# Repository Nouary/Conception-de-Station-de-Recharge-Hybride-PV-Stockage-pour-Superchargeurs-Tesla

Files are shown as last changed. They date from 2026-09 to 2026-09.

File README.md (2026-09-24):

# Conception et Dimensionnement d'une Station de Recharge Hybride (PV + Stockage) pour Superchargeurs Tesla

<p align="center">
  
  
  
  
  
  
</p>

---

## 📌 Présentation du Projet

Ce projet présente l'étude complète d'ingénierie, de dimensionnement électrotechnique, de modélisation 3D, de simulation technico-économique et de stratégie de contrôle intelligent (**Energy Management System - EMS**) pour la conversion de la **Station Supercharger Tesla** située sur la **Route de Sefrou à Fès (Maroc)**, adjacente au magasin **KITEA Giant**, en un **Hub Énergétique Hybride et Intelligent**.

<p align="center">
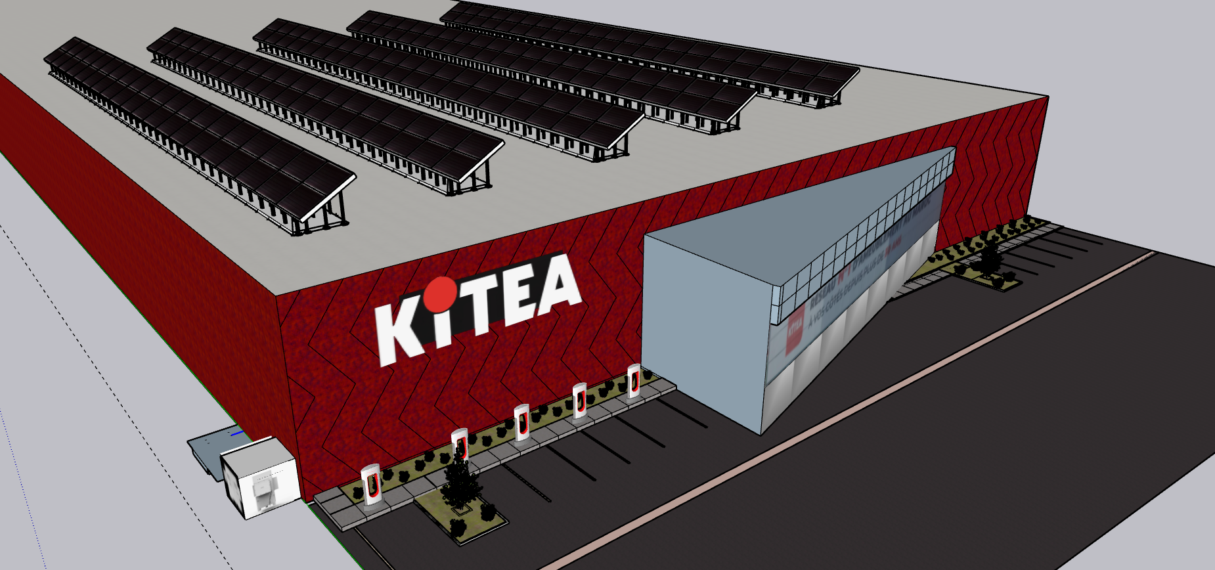
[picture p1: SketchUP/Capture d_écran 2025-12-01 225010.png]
Modélisation 3D SketchUp de la Toiture Solaire KITEA et de la Station Supercharger Tesla
  
  <br />
  <em>Modélisation 3D SketchUp : Implantation des 180 modules solaires sur la toiture KITEA Giant, conteneur BESS Huawei LUNA2000 et bornes Tesla Superchargers.</em>
</p>

### ⚠️ Problématique
Les bornes de recharge ultra-rapides Tesla (Superchargers V2/V3) délivrent des appels de puissance instantanés très élevés (**jusqu'à 150 kW par borne**). L'exploitation simultanée de ces bornes engendre :
1. **Une saturation du réseau électrique local (RADEEF)** et un risque de surcharge thermique sur le transformateur moyenne/basse tension.
2. **Des pénalités financières sévères** liées aux dépassements de la puissance souscrite lors des pointes de demande.

### 💡 Solution Proposée
Mise en place d'une architecture en **Couplage AC** exploitant la grande surface de toiture disponible du bâtiment KITEA pour la génération solaire photovoltaïque, couplée à un système de stockage par batteries industrielles (**BESS**) situé aux abords des bornes. L'ensemble est synchronisé en temps réel par un automate de gestion de l'énergie (**EMS**) assurant l'écrêtage des pointes (*Peak Shaving*) et l'arbitrage tarifaire.

---

## ⚡ Spécifications Techniques du Système

### 1. Générateur Photovoltaïque (Toiture KITEA)
* **Technologie des cellules :** Monocristallin n-type bifacial haute efficacité.
* **Modules solaires :** 180 × **JA Solar JAM66D46-LB 740 W**.
* **Puissance crête installée :** **133,2 kWc**.
* **Onduleur de chaîne :** 1 × **Huawei SUN2000-100KTL-M1** (Puissance nominale : 100 kW AC, 10 MPPT indépendants, rendement max 98,8%).
* **Configuration électrique :** 10 chaînes (*strings*) de 18 modules en série (1 chaîne par MPPT).
  * $V_{oc} \text{ à } -5^\circ\text{C} = 53,54\text{ V} \implies V_{\text{chaîne}} = 963,7\text{ V} \le 1100\text{ V}$ (Conforme).
  * $I_{sc} = 18,73\text{ A} \le I_{\text{sc max MPPT}} (40\text{ A})$ (Conforme).
  * Ratio DC/AC : $\frac{133,2\text{ kWc}}{100\text{ kW}} = \mathbf{1,33}$ (Dimensionnement optimal).

### 2. Système de Stockage d'Énergie BESS (Station Tesla)
* **Équipement :** 2 × **Huawei LUNA2000-200KWH-2H1** Smart String ESS.
* **Capacité nominale totale :** **400 kWh** (~387 kWh utiles à 90% DoD).
* **Puissance de décharge continue :** **200 kW** (Courant max : 144,3 A triphasé 400 V).
* **Convertisseurs :** Smart Rack Controller (**SRC**) stabilisant le bus DC à 1100 V et Power Conversion System (**PCS**) injectant en triphasé 400 V.
* **Autonomie :** Capacité suffisante pour assurer la recharge complète de **~6 véhicules électriques** sans solliciter le réseau.

### 3. Câblage et Raccordement Électrique
* **Liaison Toiture KITEA $\rightarrow$ Station Tesla :** Distance de **100 m**.
* **Câble de puissance AC retenu :** Câble cuivre **U-1000 R2V 4×70 mm²** (chute de tension $\Delta U < 3\%$, sécurisant la section théorique de 50 mm²).
* **Point de couplage commun (PCC) :** TGBT Station (Bus AC 400 V triphasé).
* **Protections :** Disjoncteurs boîtiers moulés (MCCB) calibrés à 160 A avec sélectivité ampèremétrique et chronométrique.

---

## 🧠 Stratégie de Contrôle Intelligent (EMS)

L'installation est pilotée par le **Huawei SmartLogger 3000A**, communicant via le protocole **Modbus-RTU (RS-485)** avec l'onduleur PV, les contrôleurs de batterie SRC et le compteur d'énergie bidirectionnel **DTSU666-H** (équipé de 3 transformateurs de courant 5A).

```
                      ┌───────────────────────────────┐
                      │    Réseau Public (RADEEF)     │
                      └──────────────┬────────────────┘
                                     │  Transformateurs de courant (TC)
                                     ▼  + Smart Power Sensor DTSU666-H
                      ┌───────────────────────────────┐
                      │    TGBT Station (Bus AC)      │
                      └───┬───────────┬───────────┬───┘
                          │           │           │
       Puissance Solaire  │           │           │  Décharge Peak Shaving
                          ▼           ▼           ▼
┌───────────────────────────┐   ┌───────────┐   ┌───────────────────────────┐
│ Onduleur Huawei           │   │  Bornes   │   │ BESS Huawei LUNA2000      │
│ SUN2000-100KTL-M1         │   │   Tesla   │   │ PCS + SRC (200 kW/400 kWh)│
│ (133.2 kWc PV Toiture)    │   │  Super-   │   └─────────────┬─────────────┘
└─────────────┬─────────────┘   │  chargers │                 │
              │                 └───────────┘                 │
              └───────────────┐               ┌───────────────┘
                     RS-485   │               │   RS-485
                              ▼               ▼
                      ┌───────────────────────────────┐
                      │   Huawei SmartLogger 3000A    │
                      │    (Cerveau EMS Centralisé)   │
                      └───────────────────────────────┘
```

### Modes de Fonctionnement Prioritaires :
1. **Écrêtage des pointes (Peak Shaving) :** Dès que la demande des Superchargeurs franchit le seuil critique contractuel (ex. 100 kW), le SmartLogger déclenche instantanément la décharge des batteries LUNA2000 à concurrence de 200 kW pour soulager le réseau.
2. **Arbitrage Tarifaire (Time-of-Use) :** Injection de l'énergie stockée durant les heures pleines/pointe en soirée pour éviter la tarification élevée du kWh.
3. **Autoconsommation & Compensation Carbone :** Priorité absolue à la consommation directe des électrons verts produits sur site.

---

## 📊 Résultats des Simulations SAM (System Advisor Model)

Les simulations de performance ont été exécutées avec le logiciel **SAM (NREL)** en utilisant les données météorologiques horaires typiques de Fès :

| Indicateur Clé (KPI) | Valeur Simulée |
| :--- | :--- |
| **Production annuelle nette AC (Année 1)** | **127 169 kWh** |
| **Ratio de Performance (PR)** | **0,77 (77,0%)** |
| **Productible spécifique** | **954 kWh/kWc** |
| **Facteur de charge DC** | **10,9%** |
| **Rendement de cycle batterie (Roundtrip)** | **96,37%** |
| **Taux de charge batterie par le système PV** | **100,0%** |

### Graphiques de Simulation

<table align="center">
  <tr>
    <td align="center" width="50%">
      <b>Diagramme des Pertes Systémiques (Sankey)</b><br />
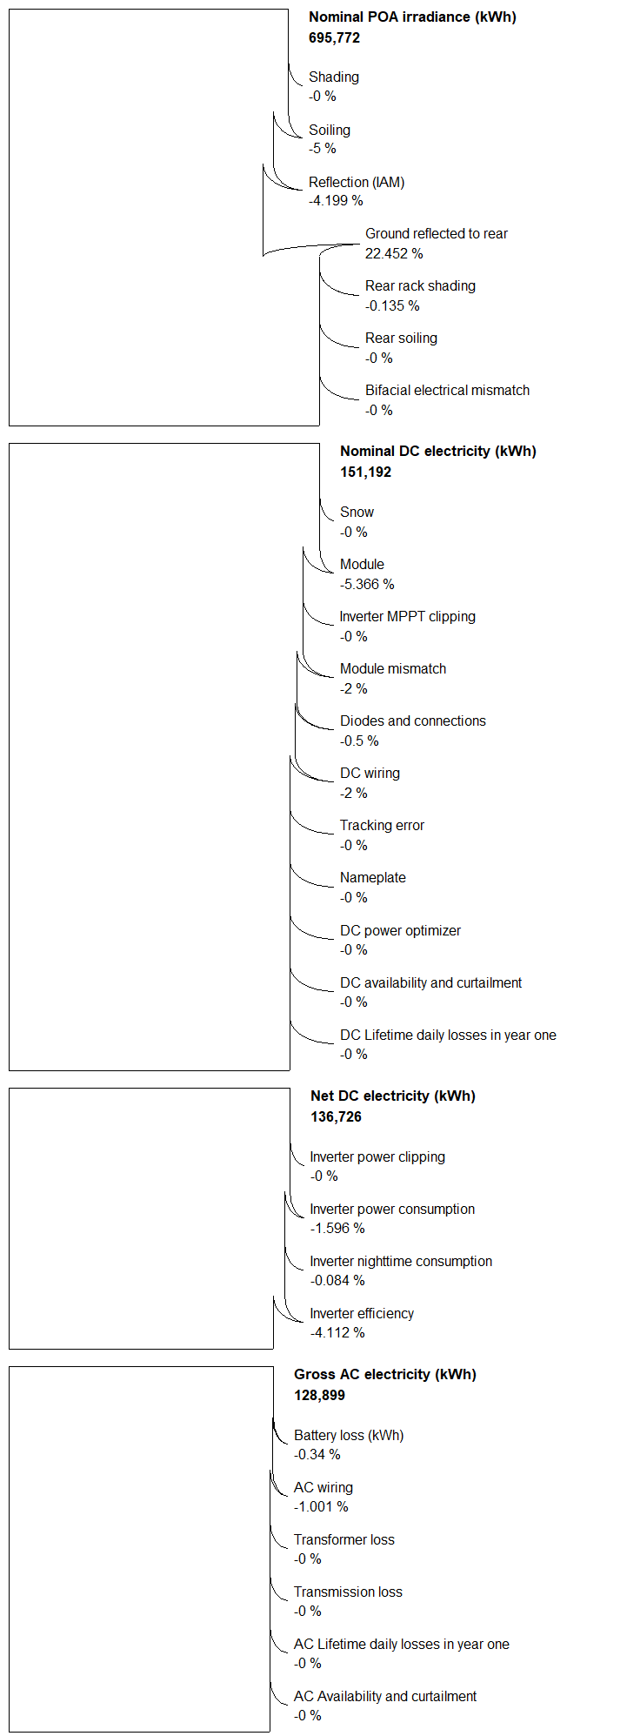
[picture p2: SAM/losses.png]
SAM System Losses
      
    </td>
    <td align="center" width="50%">
      <b>Production AC Mensuelle (Année 1)</b><br />
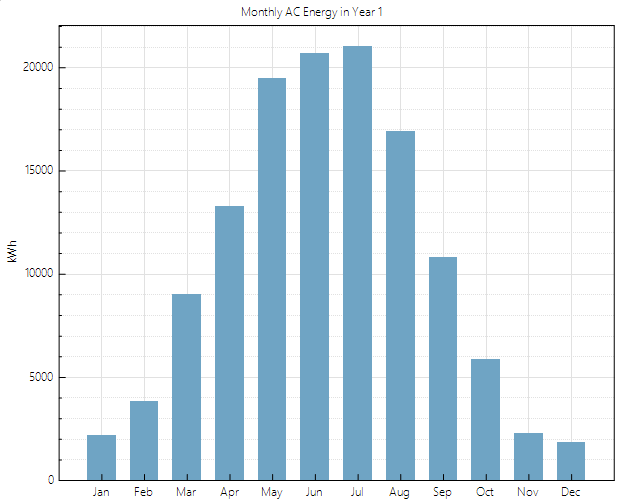
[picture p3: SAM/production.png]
Production Mensuelle
      
    </td>
  </tr>
  <tr>
    <td align="center" colspan="2">
      <b>Mix Énergétique & Couverture de la Charge (PV vs Batterie vs Réseau)</b><br />
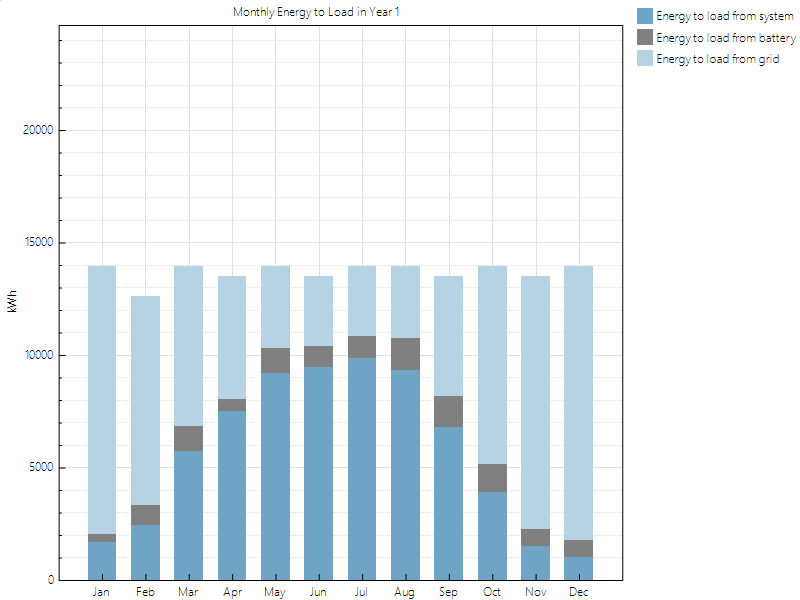
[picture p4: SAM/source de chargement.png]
Mix Énergétique
      
    </td>
  </tr>
</table>

---

## 💰 Analyse Économique & Rentabilité

### 1. Bilan d'Investissement (CAPEX)

| Désignation | Quantité | Prix Unitaire H.T. (MAD) | Montant Total H.T. (MAD) |
| :--- | :---: | :---: | :---: |
| Modules JA Solar JAM66D46-LB 740W | 180 | 1 200,00 | 216 000,00 |
| Câble solaire & AC (340 m) | 1 lot | - | 22 100,00 |
| Structure de montage toiture & brides | 1 lot | - | 106 560,00 |
| Onduleur Huawei SUN2000-100KTL-M1 | 1 | 50 000,00 | 50 000,00 |
| Huawei SmartLogger 3000A | 1 | 7 000,00 | 7 000,00 |
| Transformateurs de courant (TC) | 3 | 1 200,00 | 3 600,00 |
| Compteur intelligent DTSU666-H | 1 | 3 500,00 | 3 500,00 |
| Huawei LUNA2000-200KWH-2H1 (BESS) | 2 | 800 000,00 | 1 600 000,00 |
| Ingénierie, installation & mise en service | 1 lot | - | 159 840,00 |
| **TOTAL CAPEX H.T.** | | | **2 168 600,00 MAD** |
| **TOTAL CAPEX T.T.C. (TVA 20%)** | | | **2 602 320,00 MAD** |

### 2. Indicateurs Financiers

<p align="center">
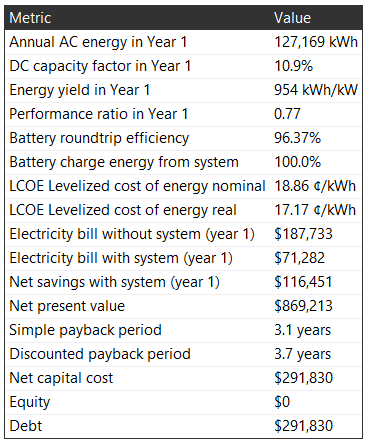
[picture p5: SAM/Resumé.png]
SAM Financial Summary
  
</p>

* **Facture d'électricité sans le système :** 2 104 502 MAD/an ($187 733 USD)
* **Facture d'électricité avec le système :** 798 438 MAD/an ($71 282 USD)
* **Économies nettes annuelles :** **1 306 064 MAD/an** ($116 451 USD)
* **Temps de retour sur investissement (Simple Payback) :** **3,1 ans** (Discounted Payback : 3,7 ans).
* **Valeur Actuelle Nette (VAN / NPV) sur 25 ans :** **+$869 213 USD** (~ 8,7 Millions MAD).
* **Coût actualisé de l'énergie (LCOE réel) :** **17,17 ¢/kWh**.

---

## 📁 Organisation du Dépôt

```plaintext
├── .gitattributes                                       # Configuration Git LFS (fichiers .skp et .skb)
├── LICENSE                                              # Licence Open-Source MIT
├── README.md                                            # Documentation générale du projet
├── Project Summary.pdf                                  # Synthèse technique et exécutive du projet
├── PV_project.pdf                                       # Rapport d'ingénierie complet détaillé (29 pages)
│
├── Autocad/                                             # Dossier des plans techniques 2D et schémas électriques
│   ├── Support 2D.pdf                                   # Plan de la structure de supportage
│   ├── Support clamps 2D.pdf                            # Détails des brides de serrage (clamps)
│   ├── schema unifilaire commande.pdf                   # Schéma unifilaire du circuit de commande
│   ├── schéma multifilaire commande.pdf                 # Schéma multifilaire de commande
│   ├── schéma unifilaire puissance.pdf                  # Schéma unifilaire du circuit de puissance
│   └── simulations/                                     # Fichiers sources AutoCAD (.dwg, .bak)
│       ├── Support 2D.dwg
│       ├── les vues de systeme.dwg
│       ├── schema unifilaire commande.dwg
│       ├── schema unifilaire puissance.dwg
│       └── schema Multiifilaire puissance.dwg
│
├── SketchUP/                                            # Modélisation 3D de la station et du bâtiment
│   ├── SketchUP.skp                                     # Maquette 3D complète (gérée via Git LFS)
│   ├── SketchUP.skb                                     # Fichier de sauvegarde SketchUp (géré via Git LFS)
│   ├── Capture d_écran 2025-12-01 224916.png            # Rendu toiture KITEA et panneaux
│   └── Capture d_écran 2025-12-01 225010.png            # Rendu complet toiture, station Tesla et BESS
│
├── SAM/                                                 # Modélisation et simulation NREL SAM
│   ├── SAM FINAL.sam                                    # Projet source System Advisor Model
│   ├── losses.png                                       # Diagramme de pertes en cascade (Sankey)
│   ├── production.png                                   # Graphique de production mensuelle AC
│   ├── source de chargement.png                         # Répartition de couverture de charge
│   ├── Resumé.png                                       # Tableau récapitulatif des métriques financières
│   ├── inverter data/                                   # Fiches de caractérisation de l'onduleur (.csv)
│   └── module data/                                     # Fiches de caractérisation des modules (.csv)
│
└── Data sheet and user manual/                          # Fiches techniques et manuels officiels
    ├── SUN2000-100KTL-M1.pdf                            # Onduleur triphasé Huawei 100 kW
    ├── luna2000-200kwhg-2h1-dtatsheet-20230310.pdf      # Système de stockage industriel Huawei LUNA2000
    ├── SmartLogger3000A.pdf                             # Fiche technique du contrôleur de communication
    ├── Manuel d_utilisation, SmartLogger3000.pdf        # Manuel complet d'utilisation SmartLogger
    ├── JAM66D46_715-740_LB_Global_EN_20250709C.pdf      # Module solaire JA Solar 740 W
    ├── dtsu666-h-100a-datasheet.pdf                     # Capteur de puissance intelligent Huawei / Chint
    └── DTSU666-H 100 A and 250 A Smart Power Sensor...  # Manuel de câblage et configuration du compteur
```

---

## 👥 Auteurs & Affiliation Académique

Projet d'ingénierie réalisé au sein de :
* **Institution :** École Nationale des Sciences Appliquées de Fès (**ENSA Fès**) — Université Sidi Mohamed Ben Abdellah (**USMBA**).
* **Département :** Génie Industriel.
* **Filière :** Génie Énergétique et Systèmes Intelligents (**GESI**).
* **Module :** Énergie Solaire Photovoltaïque.

**Auteurs du projet :**
* **NOUARY Lhoussaine** ([@Nouary](https://github.com/Nouary))
* **AZZOUZI Wassim**
* **SAADANI Aymane**

**Sous l'encadrement de :**
* **M. CHAIBI Yassine**

---

## 📄 Licence

Ce projet est sous licence libre et open-source **[MIT](LICENSE)**. Vous êtes libre de consulter, utiliser, adapter et vous inspirer de ces travaux pour vos projets académiques et industriels, sous réserve de mentionner les auteurs originaux.

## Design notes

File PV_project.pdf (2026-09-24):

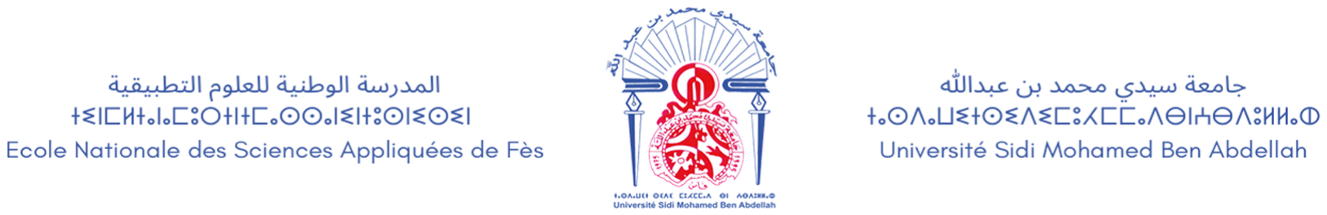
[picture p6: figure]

Département Génie Industriel

FIlière Génie Energétique et Systèmes Intelligents

Energie Solaire Photovoltaique

# Conception et Dimensionnement d’une Station de Recharge Hybride (PV + Stockage) : Stratégie de Gestion Intelligente pour Superchargeurs Tesla

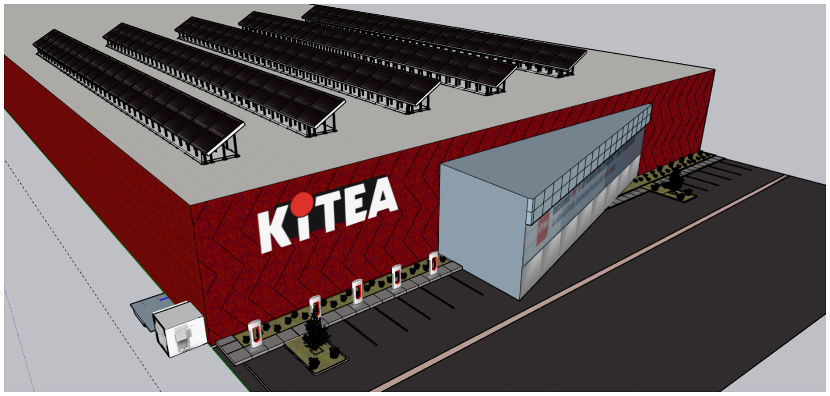
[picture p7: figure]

Réalisé par :

### AZZOUZI Wassim NOUARY Lhoussaine SAADANI Aymane

Encadré par :

### M.CHAIBI Yassine

# Table des matières

1 Introduction | 3
2 Cahier de charges et Dimensionnement du système | 5
3 Étude de compatibilité et vérifications électriques | 12
4 Systèmes intelligents et communications | 15

4.5 Raccordement du compteur DTS U666-H et intégration au SmartLogger . 17

5 Simulation et résultats | 18
6 Etude économique | 27
7 Conclusion | 28

# Table des figures

2.1 Vue de la station Supercharger Tesla à Fès, adjacente au magasin KITEA

2.2 Panneau solaire JA Solar de type JAM66D46 d’une puissance nominale de

2.3 Système de Stockage d’Énergie (ESS) LUNA2000-200KWH-2H1 de Huawei

2.4 Onduleur de type Huawei SUN2000-100KTL-M1 de puissance nominale de

3.1 Schéma illustratif du flux énergétique entre les batteries, le SRC et le PCS. 14

5.1 Plan de calepinage de la toiture KITEA et positionnement des équipements. 18

5.3 Schéma électrique Multifilaire détaillé (Liaison Zone 1 Toiture - Zone 2

5.4 Architecture du système de contrôle-commande (SmartLogger et communi-

5.5 Synoptique des flux de puissance : Production, Stockage et Consommation. 22 5.6 Diagramme des pertes du système (Irradiance POA vers Énergie AC Nette). 23

5.8 Répartition mensuelle de la couverture de charge (PV vs Batterie vs Réseau). 25

# Liste des tableaux

# Chapitre 1

# Introduction

## 1.1 Contexte

La Station Supercharger Tesla de la Route de Sefrou à Fès, adjacente au magasin KITEA Giant, constitue un point stratégique pour la mobilité électrique dans la région. Équipée de bornes de recharge ultra-rapides (Superchargers V2/V3), la station est capable de délivrer jusqu’à 150 kW par borne de recharge, permettant une recharge très rapide pour les utilisateurs de véhicules électriques.
Ces charges massives créent des contraintes sur le réseau électrique local et peuvent engendrer des coûts importants pour l’opérateur en cas de dépassement de puissance. Face à ces défis, l’intégration d’une solution hybride combinant production solaire et stockage d’énergie apparaît comme une approche stratégique. Elle permet non seulement de réduire la dépendance au réseau, mais aussi d’améliorer la durabilité énergétique et de contribuer aux objectifs de transition énergétique régionale.

## 1.2 Problématique et objectifs

L’exploitation de la station telle qu’elle existe actuellement présente deux principaux défis :
— Saturation du réseau : Le transformateur local risque d’être surchargé lors des recharges simultanées.
— Coûts élevés : Les pénalités liées aux dépassements de puissance augmentent significativement les factures d’électricité.
L’objectif de ce projet est de concevoir une station de recharge hybride intelligente combinant production solaire et stockage industriel, afin de :
— Réduire la charge instantanée sur le réseau.
— Optimiser l’usage de l’énergie renouvelable.
— Minimiser les coûts d’exploitation tout en favorisant une approche durable.

## 1.3 Méthodologie

Pour atteindre ces objectifs, le projet a suivi les étapes suivantes :
1. Étude du site : Analyse de la demande en énergie et des caractéristiques des bornes Tesla.

2. Dimensionnement du système photovoltaïque : Calcul de la capacité nécessaire pour la production solaire sur la toiture du KITEA.
3. Conception du stockage industriel : Sélection des batteries et définition de leur puissance et autonomie pour répondre aux besoins de pointe.
4. Intégration et gestion intelligente : Développement d’une stratégie EMS (Energy Management System) pour piloter le peak shaving, l’arbitrage et la compensation carbone.

# Chapitre 2

# Cahier de charges et Dimensionnement du système

## 2.1 Cahier de charges

— Localisation du projet : Station Supercharger Tesla située sur la Route de Sefrou à Fès, adjacente au magasin KITEA Giant.
— Nombre de véhicules souhaités rechargés par jour via l’énergie photovoltaïque : 10 véhicules par jour.
— Support d’installation photovoltaïque : Utilisation de la toiture du magasin KITEA pour l’installation du champ solaire.
— Rentabilité du projet :
— Réduction des coûts énergétiques grâce à l’autoconsommation solaire.
— Diminution des pénalités liées au dépassement de puissance.
— Amélioration du retour sur investissement grâce à une production solaire gratuite et à la baisse de la dépendance vis-à-vis du réseau électrique.
— Valorisation environnementale et amélioration de l’image « verte » de la station.

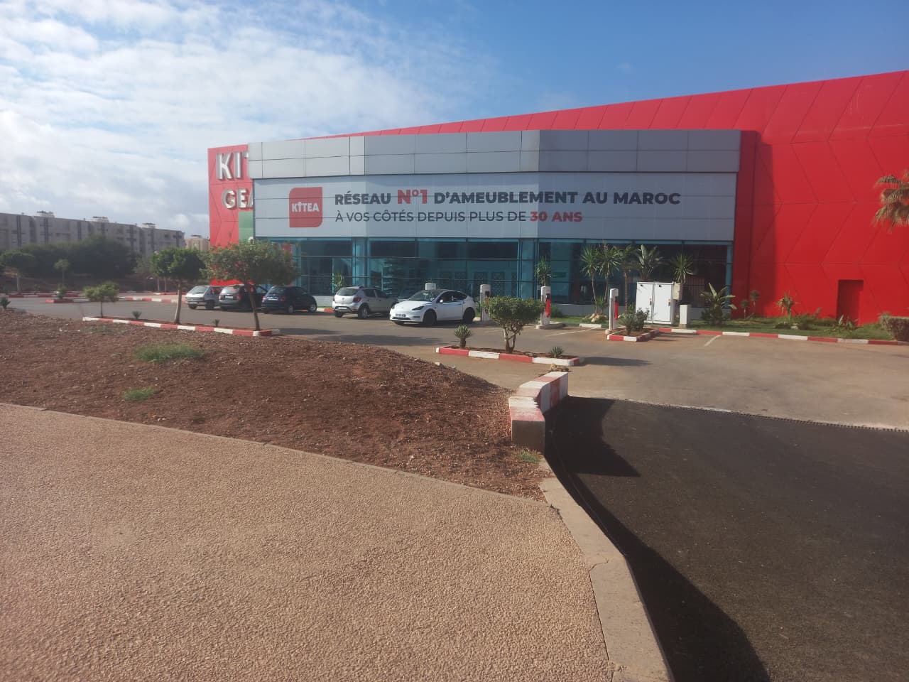
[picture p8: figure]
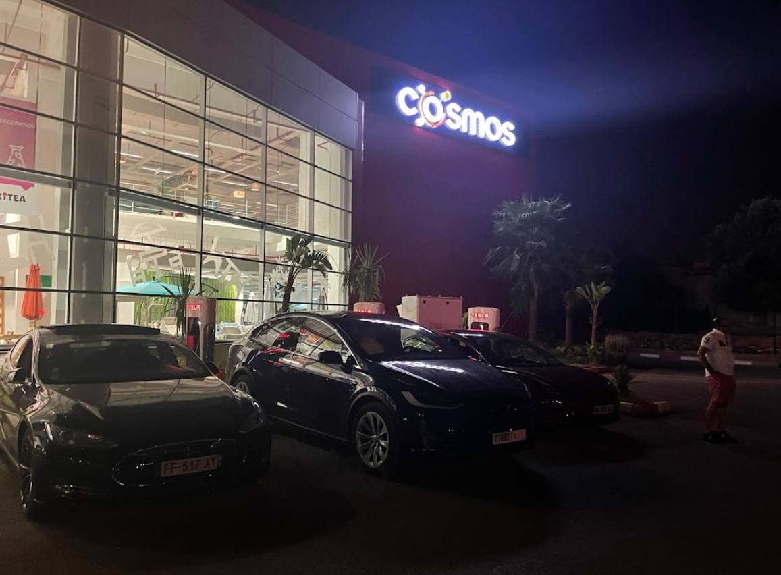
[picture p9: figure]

Figure 2.1 – Vue de la station Supercharger Tesla à Fès, adjacente au magasin KITEA Giant.

## 2.2 Dimensionnement PV

Le besoin énergétique journalier pour les véhicules électriques est donné par la formule :

Ejournalière = N × Ccharg × ∆(%)

où :
— N : nombre de véhicules électriques par jour,
— Ccharg : capacité de charge d’un véhicule (kW h),
— ∆(%) : variation de charge, c’est-à-dire la différence entre le pourcentage avant et après la charge.

Ejournalière = 10 × 75 × 0, 6

Ejournalière = 450 kWh/jour

### 2.2.1 Choix des modules

Calcul de la puissance crête totale

La puissance crête totale du système PV est donnée par la formule :

Pcrête =

Ej
Girr × P R
où :
— Ej

: énergie journalière nécessaire pour les VE (kWh/jour), — Girr : irradiation solaire moyenne journalière (kW h m⁻² d

−1
),
— P R : performance ratio (rendement global du système PV, sans unité) On obtient :

Pcrête =

450 000
5 250 × 0, 7

=

450 000
4 125

Pcrête ≈ 133.2 kWc

Nombres de modules photovoltaïques

Pour le champ solaire, nous avons retenu les modules JA Solar de type JAM66D46-LB d’une puissance nominale de 740 W (STC).

Données retenues :
— Puissance totale souhaitée du générateur : 133.2 kWc.
— Puissance unitaire d’un module : 740 W.
Calcul du nombre de modules :

Npanneaux =

133 200 W
740 W/module ≈ 180 modules

Npanneaux = 180 modules

=> Il faudra environ 180 modules pour atteindre la puissance crête désirée de 133.2 kWc.

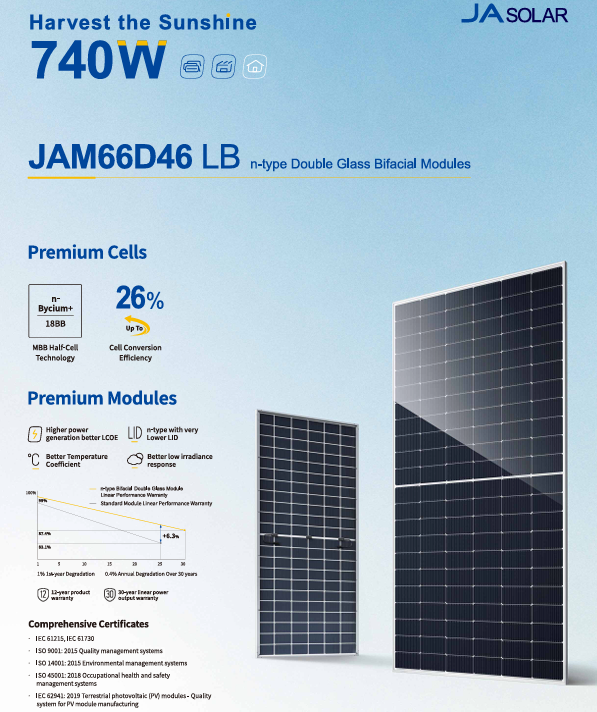
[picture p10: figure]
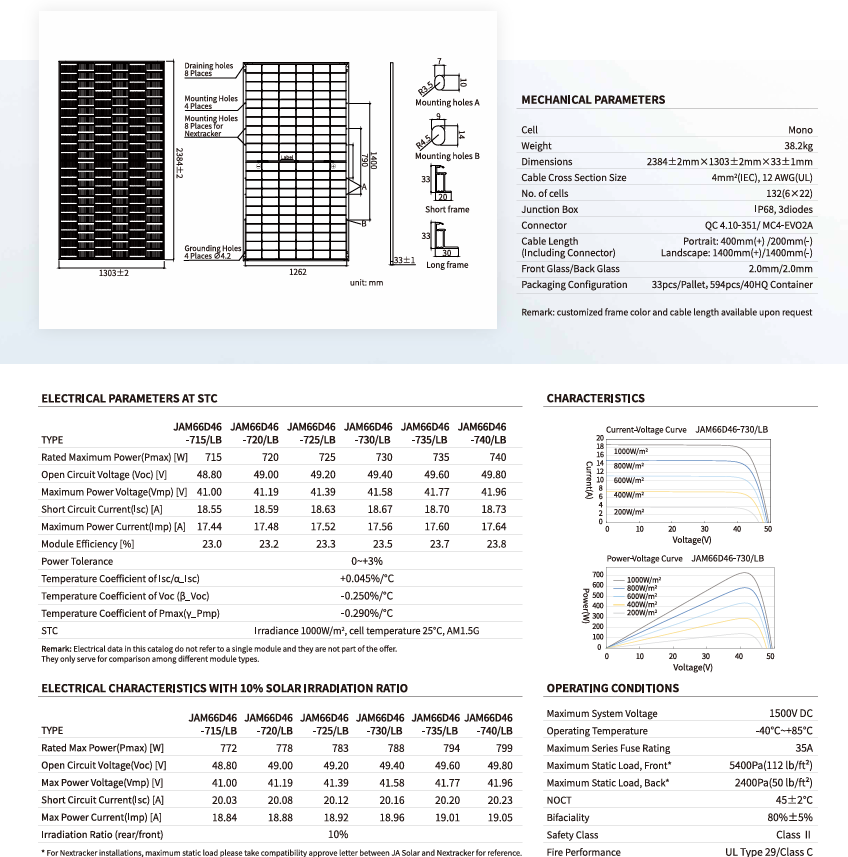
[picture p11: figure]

Figure 2.2 – Panneau solaire JA Solar de type JAM66D46 d’une puissance nominale de 740 W (STC) et sa fiche technique.

## 2.3 Dimensionnement batterie

Pour le dimensionnement du stockage, nous considérons que la batterie doit couvrir : — 30% du besoin journalier pour la nuit,
— 30% supplémentaire pour augmenter la puissance disponible lors des pointes de charge.

### Énergie d’autonomie

L’énergie nécessaire pour l’autonomie est calculée à partir de l’énergie journalière estimée :

Eautonomy = 0.6 × Ejournalier = 0.6 × 450 = 270 kWh

### Capacité nominale des batteries

La capacité totale des batteries est donnée par la formule :

CBatt =

Eautonomy

DoD × ηBatt × ηinv
Avec :
— DoD (Depth of Discharge) ≈ 90% = 0.9 — Rendement batterie : ηBatt = 0.95
— Rendement onduleur : ηinv = 0.96

CBatt =

270 000
0.9 × 0.95 × 0.96

≈ 328.9 kWh

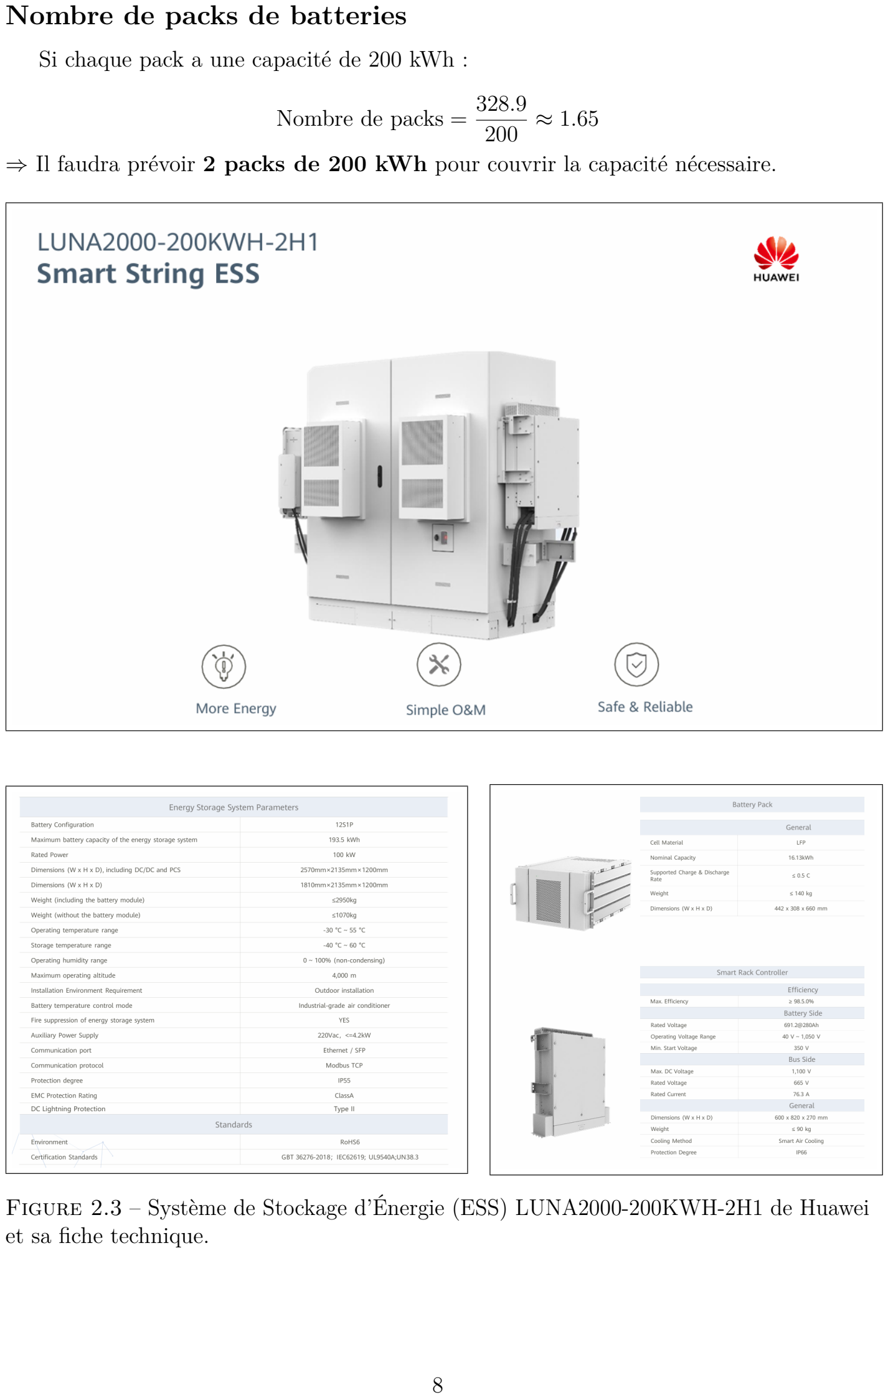
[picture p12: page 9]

### Nombre de packs de batteries

Si chaque pack a une capacité de 200 kWh :

Nombre de packs =

328.9
200

≈ 1.65

⇒ Il faudra prévoir 2 packs de 200 kWh pour couvrir la capacité nécessaire.

Figure 2.3 – Système de Stockage d’Énergie (ESS) LUNA2000-200KWH-2H1 de Huawei et sa fiche technique.

## 2.4 Onduleur et convertisseurs

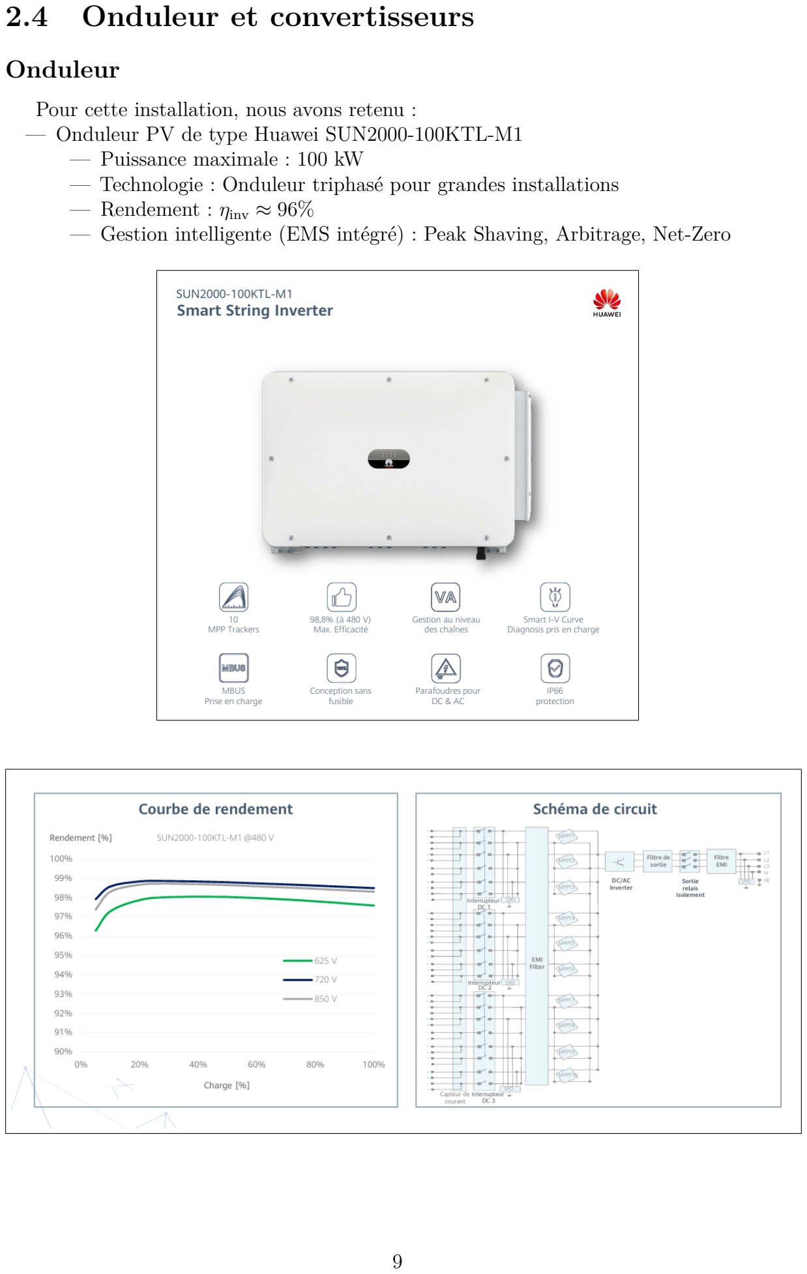
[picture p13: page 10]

### Onduleur

Pour cette installation, nous avons retenu :
— Onduleur PV de type Huawei SUN2000-100KTL-M1
— Puissance maximale : 100 kW
— Technologie : Onduleur triphasé pour grandes installations
— Rendement : ηinv ≈ 96%
— Gestion intelligente (EMS intégré) : Peak Shaving, Arbitrage, Net-Zero

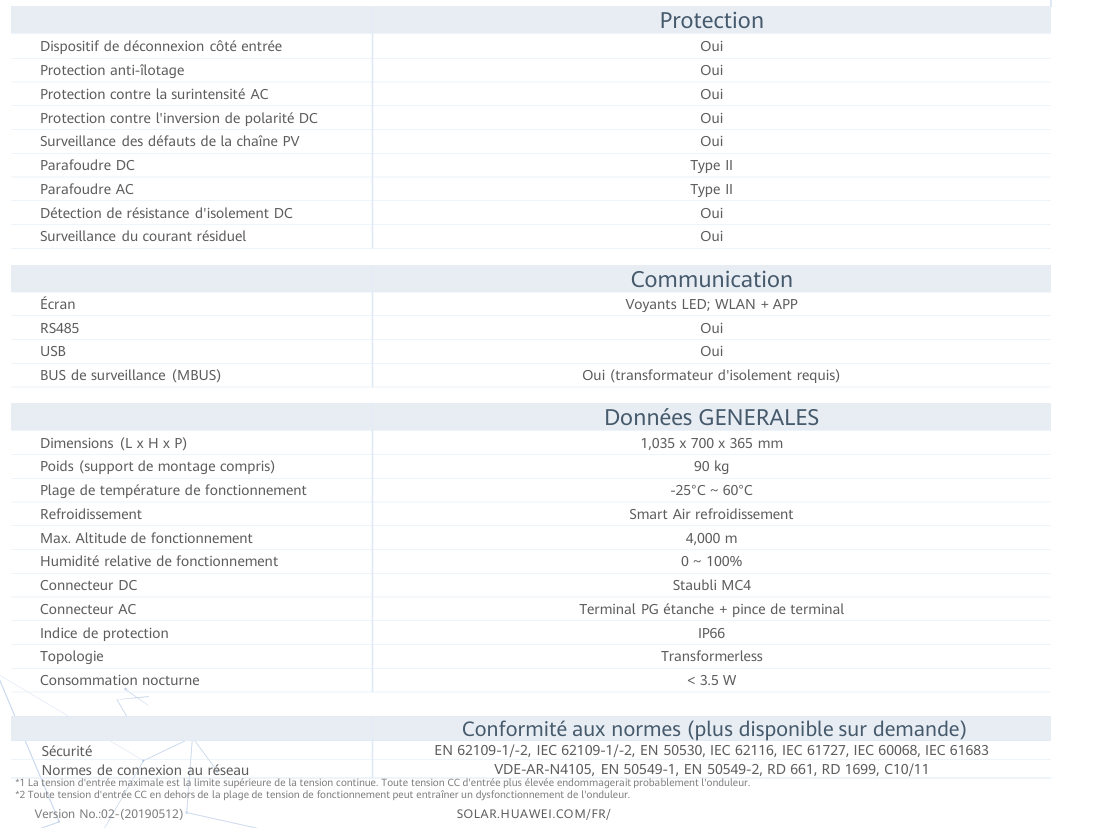
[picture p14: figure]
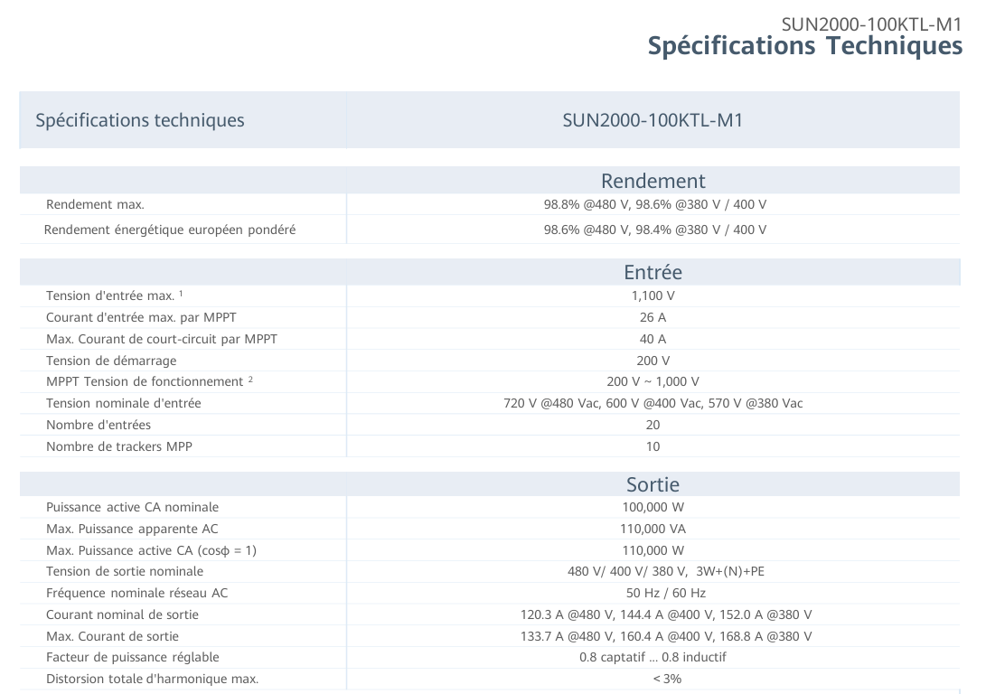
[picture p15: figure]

Figure 2.4 – Onduleur de type Huawei SUN2000-100KTL-M1 de puissance nominale de 100kW et sa fiche technique.

### Convertisseur batterie / AC

— le convertisseur est intégré dans le pack Huawei LUNA2000 — Puissance de sortie : 200 kW (Peak Shaving)
— Capacité de décharge pour lisser les pointes du réseau — Compatibilité avec le bus AC commun de la station

## 2.5 Dimensionnement des câbles

Le dimensionnement des câbles AC permet d’assurer la sécurité, de limiter les pertes et de respecter la chute de tension admissible.

### Formules de base

Pour un câble triphasé, la chute de tension entriphase est donnée par :

∆U =

√
3 · I · R · cos ϕ

où :
— I : courant maximal (A)
— R : résistance du câble ()
— cos ϕ : facteur de puissance
La résistance du câble est calculée par :

R =

L
γ · S
avec :
— L : longueur du câble (m)
— γ : conductivité du conducteur (S·m/mm²), cuivre ≈ 56
— S : section du câble (mm²)
En combinant les deux formules, la section minimale du câble est :

S =

√
3 · Imax · L · cos ϕ
γ · ∆U

### Données du projet

— Puissance maximale du convertisseur batterie : Pmax = 200 kW — Tension nominale triphasée : Unominale = 480 V
— Longueur du câble : L = 100 m
— Facteur de puissance : cos ϕ = 0.95
— Chute de tension admissible : ∆U = 3% × 480 V = 14.4 V — Conductivité du cuivre : γ = 56 S·m/mm²

### Calcul du courant maximal

Imax =

Pmax √

3 · Unominale · cos ϕ

=

200 000
√
3 · 480 · 0.95

≈ 253.3 A

### Calcul de la section du câble

S =

√
3 · Imax · L · cos ϕ
γ · ∆U

=

√
3 · 253.3 · 100 · 0.95
56 · 14.4

≈ 51.7 mm²

⇒ La section standard retenue : 4 × 50 mm² cuivre.

# Chapitre 3

# Étude de compatibilité et vérifications électriques

## 3.1 Compatibilité PV - onduleur (tension/courant)

### Données des panneaux

— Panneau : JA Solar 740 Wc
— Tension à vide à 25°C : Voc = 49.8 V
— Coefficient de température : α = −0.25%/řC = −0.0025/řC — Température minimale : −5

◦C

### Données de l’onduleur

— Tension nominale MPPT : 720 V — Plage MPPT : 800 – 1000 V
— Tension maximale : 1100 V

### Calcul de la tension à froid

La tension à -5°C est calculée par la formule :

V (T) = Voc(25◦C) × [1 + α · (T − 25)]

V (−5

◦C) = 49.8 × [1 + (−0.0025) · (−30)] ≈ 53.54 V

### Nombre de panneaux en série

— Nombre maximal de panneaux en série :

Nmax série =

Vmax onduleur
V (−5

◦C)

=

1100
53.54

≈ 20 panneaux max

— Nombre minimal de panneaux en série : En considérant la tension maximale du panneau à haute température (ex. 45°C) :

Voc(45◦C) = 49.8 × (1 − 0.0025 · 20) ≈ 47.31 V

Nmin série =

VMPPT min
Voc(45◦C)

=

800
47.31

≈ 17 panneaux min

— Nombre optimal de panneaux :

Noptimal = 18 panneaux en série

## 3.2 Vérification Courant et Puissance PV

### Données des panneaux

— Panneau : JA Solar 740 Wc
— Courant nominal : Inominal = 17, 64 A — Courant de court-circuit : Isc = 18, 73 A

### Données de l’onduleur

— Courant maximal MPPT : Isc max = 40 A — Courant maximal MPPT : Imp max = 26 A — Nombre de MPPT : 10

### Vérification courant par chaîne

Chaque MPPT reçoit une seule chaîne de 18 panneaux :

Ichaîne = Isc = 18, 73 A ≤ Isc max = 40 A ✓

### Nombre total de panneaux et puissance PV

Nombre total de panneaux = 18 × 10 = 180 panneaux

PPV = 180 × 740 W = 133, 2 kWc

### Ratio DC/AC

Onduleur AC = 100 kW | ⇒ | DC/AC =

133, 2
100

= 1, 33 ✓

La configuration retenue respecte les contraintes électriques de l’onduleur, le courant par chaîne reste inférieur à la limite maximale et le ratio DC/AC est conforme aux standards de conception. Ainsi, 180 panneaux PV répartis sur 10 MPPT avec 18 panneaux par chaîne assurent une puissance totale de 133,2 kWc adaptée à l’installation.

## 3.3 Système de Stockage

### Flux énergétique

Le Smart Rack Controller (SRC) stabilise la tension DC à 1100 V pour l’alimentation de l’onduleur et la gestion des MPPT. Le PCS convertit la tension DC en AC triphasé 400 V pour la distribution vers les bornes de recharge.

Batteries → Smart Rack Controller (SRC) → Power Conversion System (PCS) → AC 400 V triphasé

Figure 3.1 – Schéma illustratif du flux énergétique entre les batteries, le SRC et le PCS.

### Dimensionnement des batteries

Besoin en capacité Pour couvrir 30% du besoin durant la nuit et 30% de puissance pour lisser les pointes :

Eautonomy = 0, 6 × Ejournalier = 0, 6 × 450 = 270 kWh

Choix du matériel
— Pack batterie : Huawei LUNA2000-200kWh-2H1
— Capacité unitaire : 200 kWh
— Nombre de packs : 2 → Capacité totale ≈ 400 kWh : Ceci permet de répondre à l’autonomie nécessaire et aux besoins de peak shaving.

### Sorties du système

— Sortie du PCS : Un = 400 V triphasé AC, Imax = 144, 3 A — Sortie du SRC : UDC = 1100 V

### Dimensionnement pour la borne de recharge

- Borne Tesla : puissance maximale 150 kW - Puissance PV disponible : 100 kW -Supplément fourni par les batteries : 50 kW pour atteindre la puissance maximale lors du peak demand.
La configuration choisie avec 2 packs Huawei LUNA2000-200kWh fournit une capacité suffisante pour l’autonomie nocturne et le lissage des pointes, tout en respectant les contraintes de tension et courant du système.

# Chapitre 4

# Systèmes intelligents et communications

## 4.1 Transformateurs de courant (TC)

— 3 unités, une par phase, pour mesurer le courant du réseau.
— Entrée secondaire : 5 A pour une tension primaire jusqu’à 600 V.
— Fonctionnement : Mesurent le flux de courant du réseau vers la station et la production PV. Fournissent des signaux proportionnels au courant réel pour les systèmes de contrôle et de protection.

## 4.2 SmartLogger 3000A

— Centralise les données de production PV, de consommation et des batteries.
— Fonctionnement : Analyse en temps réel les données, pilote l’EMS pour le peak shaving, l’arbitrage énergétique et la compensation Net-Zero. Permet la communication avec tous les équipements via ModBUS RTU.

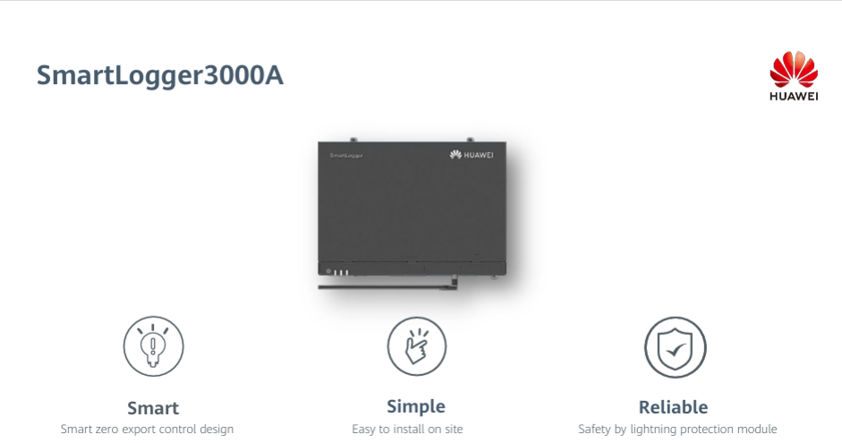
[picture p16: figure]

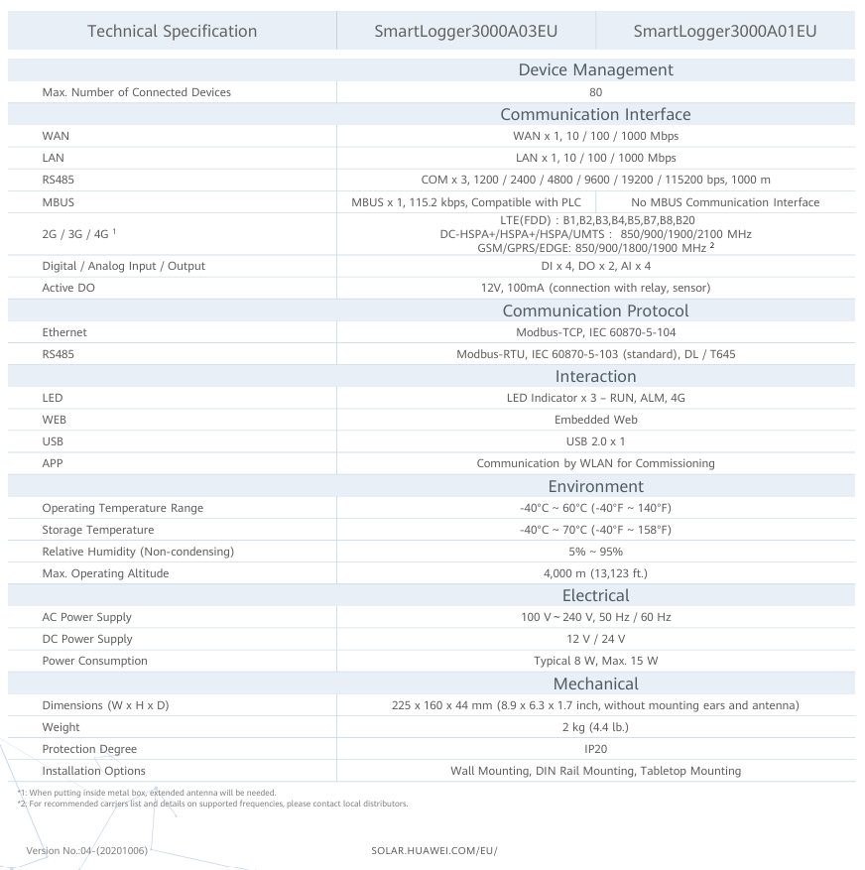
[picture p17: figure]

Figure 4.1 – SmartLogger 3000A

## 4.3 Onduleur PV (Huawei SUN2000)

— Convertit la puissance DC des panneaux PV en AC pour le réseau de la station. — Fonctionnement : Optimise le point de puissance maximale (MPPT), communique avec le SmartLogger pour ajuster la production selon la demande et les contraintes réseau.

## 4.4 Compteurs DTS U666-H / Smart Power Sensor

— Mesurent la puissance active, réactive et le facteur de puissance.
— Fonctionnement : Fournissent des mesures précises au SmartLogger pour le suivi en temps réel et la gestion intelligente de l’énergie de la station.

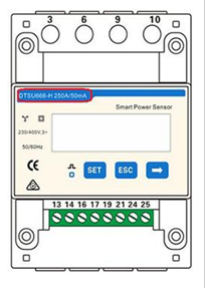
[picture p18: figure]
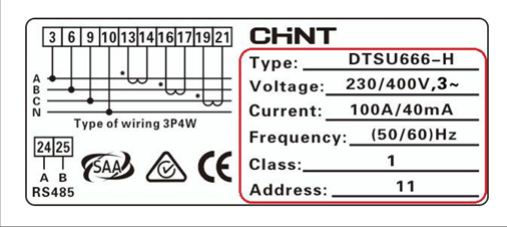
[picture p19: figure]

Figure 4.2 – Compteurs DTS U666-H / Smart Power Sensor.

## 4.5 Raccordement du compteur DTS U666-H et intégration au SmartLogger

### Connexions électriques

1. Brancher les 3 phases (L1, L2, L3) et le neutre (N) depuis le jeu de barres vers le compteur.
2. Installer des fusibles de protection (2 A / 10 A) sur chaque phase avant l’entrée du compteur.
3. Vérifier la tension de référence pour assurer des mesures correctes.
4. Relier les fils secondaires des transformateurs de courant (TC1, TC2, TC3) aux entrées correspondantes du compteur.
5. Connecter le compteur au SmartLogger 3000A via l’interface de communication (ModBUS RTU).

### Flux d’information et fonctionnement

— Entrées compteur : L1, L2, L3, N
— Sorties compteur : A, B → connectées au SmartLogger
— Le SmartLogger reçoit les mesures de courant et de puissance du compteur et compare ces valeurs à la puissance de consigne (ex. 100 kW).
— En cas de déficit ou dépassement, le SmartLogger commande le déchargement des batteries ou ajuste la production PV via l’onduleur pour maintenir la puissance cible.

# Chapitre 5

# Simulation et résultats

## 5.1 Implantation Photovoltaïque

L’implantation des modules sur la toiture du bâtiment KITEA a été optimisée pour maximiser la puissance installée tout en respectant les contraintes d’exploitation. Le plan de masse ci-dessous illustre la disposition des chaînes en mode portrait, avec des allées de maintenance de 1500mm pour garantir l’accès sécurisé aux équipements. Le positionnement des batteries (2x Huawei LUNA) et des bornes de recharge a été défini pour minimiser les longueurs de câbles vers le TGBT.

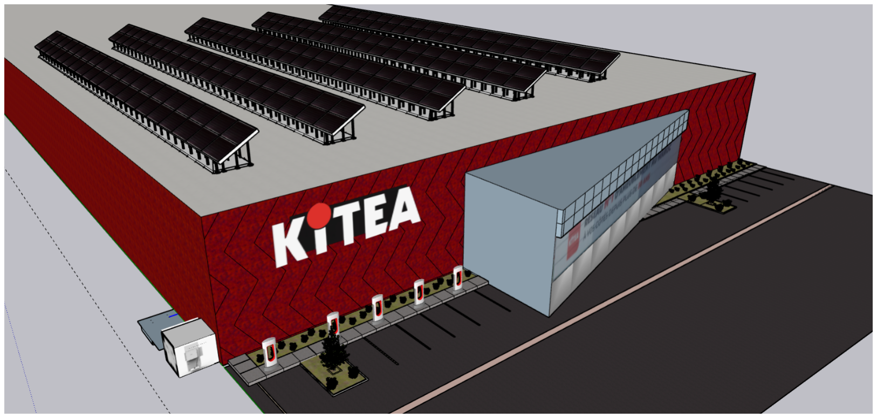
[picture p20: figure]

Figure 5.1 – Plan de calepinage de la toiture KITEA et positionnement des équipements.

Le système de fixation retenu assure la pérennité mécanique de l’installation face aux charges de vent. Le détail ci-après montre les brides de fixation inter-modules (middle clamps) garantissant l’espacement normé et la mise à la terre du cadre aluminium.

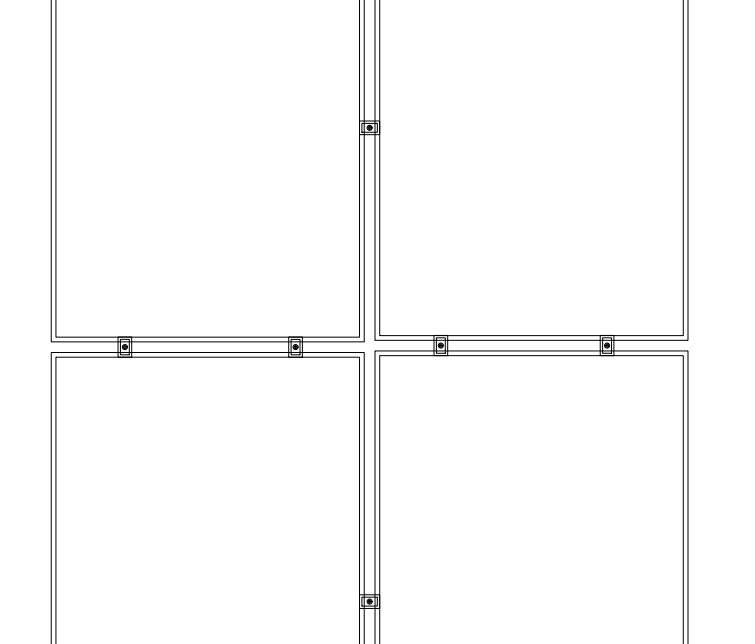
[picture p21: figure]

Figure 5.2 – Détail technique des brides de fixation des modules.

## 5.2 Ingénierie Électrique et Schémas Normalisés (AutoCAD)

### 5.2.1 Architecture Unifilaire et Dimensionnement AC/DC

L’architecture électrique du projet a été conçue en mode Couplage AC, permettant une flexibilité optimale entre la production solaire et le stockage. Comme illustré sur le schéma unifilaire général ci-dessous, l’installation est divisée en deux zones distinctes : — Zone 1 (Toiture KITEA) : Elle regroupe les 10 chaînes (strings) de modules PV connectées à l’onduleur de chaîne Huawei SUN2000-100KTL.
— Zone 2 (Station Tesla) : Elle abrite le TGBT principal où convergent l’arrivée du réseau RADEEF, le système de stockage (ESS) et les bornes de recharge.
Une attention particulière a été portée au dimensionnement des câbles de puissance pour limiter la chute de tension à moins de 3% malgré la distance. La liaison entre l’onduleur et le TGBT est assurée par un câble U-1000 R2V 4x70 mm², offrant une marge de sécurité par rapport à la section théorique calculée de 50 mm². Les protections sont étagées via des disjoncteurs boîtiers moulés (MCCB) de 160A pour garantir la sélectivité.

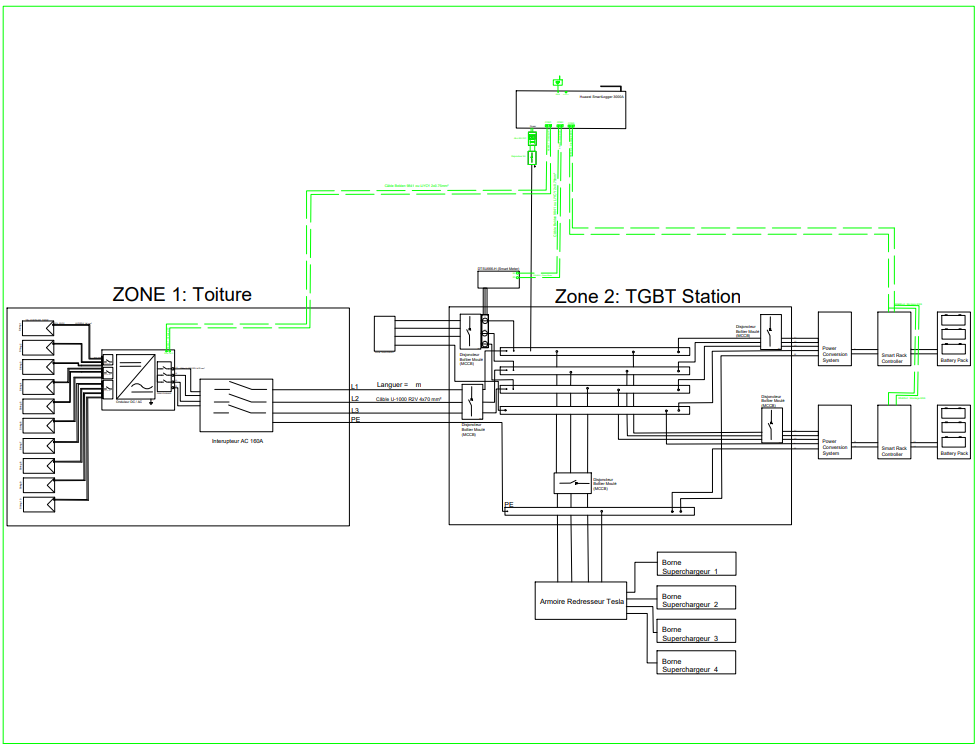
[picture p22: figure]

Figure 5.3 – Schéma électrique Multifilaire détaillé (Liaison Zone 1 Toiture - Zone 2 Station).

### 5.2.2 Synoptique du Circuit de Commande et Communication

La gestion intelligente des flux énergétiques (EMS) repose sur l’intégration du Smart-Logger 3000A de Huawei. Ce contrôleur central agit comme le "cerveau" de l’installation en communiquant via le protocole Modbus-RTU (RS485) avec les différents organes du système : l’onduleur PV, les contrôleurs de batteries (Smart Rack Controllers) et le compteur intelligent (Power Meter).
Le schéma de commande ci-dessous détaille cette boucle de communication qui permet : — La remontée des données de production et de consommation en temps réel.
— Le pilotage de la charge/décharge des batteries pour l’écrêtage des pointes (Peak Shaving).
— La régulation de la puissance injectée pour éviter la saturation du transformateur.

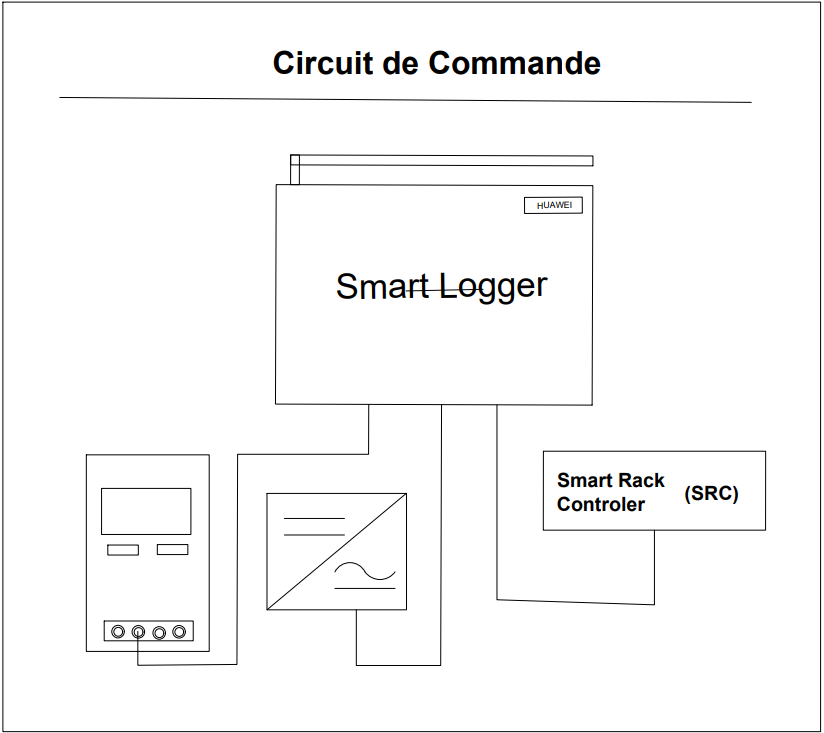
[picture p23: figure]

Figure 5.4 – Architecture du système de contrôle-commande (SmartLogger et communication).

### 5.2.3 Analyse des Flux : Circuit de Puissance

Le circuit de puissance a été modélisé pour visualiser l’interaction entre les sources d’énergie et les charges critiques (Superchargeurs). Le diagramme ci-après distingue clairement le bloc "Production" (Champs PV et Réseau) du bloc "Consommation". L’interfaçage est assuré par le Power Conversion System (PCS) des batteries LUNA2000 qui joue un rôle tampon. En cas de forte sollicitation des bornes Tesla (appel de puissance > 100 kW), le système puise simultanément dans la production solaire instantanée et le stockage, soulageant ainsi le transformateur de distribution.

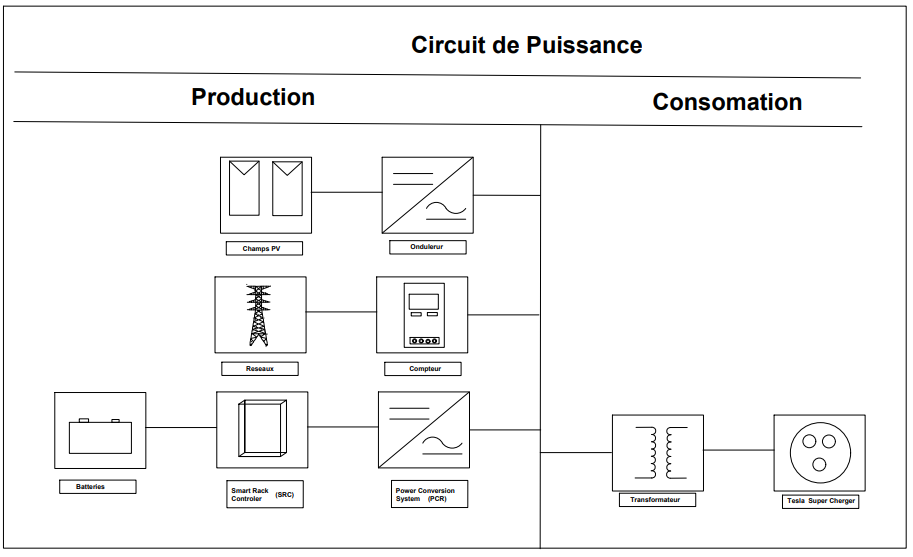
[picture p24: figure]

Figure 5.5 – Synoptique des flux de puissance : Production, Stockage et Consommation.

## 5.3 Simulation de Performance et Productible (SAM)

### 5.3.1 Analyse des Pertes Systémiques

La simulation SAM débute par une analyse détaillée des pertes, depuis l’irradiation incidente jusqu’à l’injection AC. Comme le montre le diagramme de flux (Sankey) ci-dessous, le productible théorique est impacté par plusieurs facteurs physiques et environnementaux réalistes pour la région de Fès :
— Encrassement (Soiling) : Une perte de 5% a été considérée, prenant en compte l’empoussièrement naturel du site et la fréquence de nettoyage.
— Conversion DC/AC : L’onduleur Huawei présente un rendement élevé, avec des pertes de conversion limitées à environ 4.1%.
— Pertes Câblage : Les pertes ohmiques (AC et DC) sont maintenues sous les 3% grâce au surdimensionnement des sections de câbles (70mm²).
Le ratio de performance global (PR) qui en résulte est de 0.77, une valeur performante pour un système hybride avec stockage fonctionnant sous des températures ambiantes élevées.


Figure 5.6 – Diagramme des pertes du système (Irradiance POA vers Énergie AC Nette).

### 5.3.2 Profil de Production Mensuelle

La production électrique suit la courbe d’ensoleillement typique du Maroc. Le graphique ci-dessous illustre une forte saisonnalité :
— Période Estivale (Mai - Août) : La production dépasse les 20 MWh par mois, coïncidant potentiellement avec les pics de fréquentation touristique et l’usage intensif de la climatisation du centre commercial voisin.
— Période Hivernale : La production baisse significativement (autour de 3-5 MWh en Décembre/Janvier), nécessitant un apport plus conséquent du réseau RADEEF durant ces mois.
Le cumul annuel atteint 127 169 kWh (pour l’année 1), confirmant la capacité du générateur de 133 kWc à couvrir une part majeure des besoins énergétiques.


Figure 5.7 – Production d’énergie AC mensuelle simulée (Année 1).

### 5.3.3 Stratégie de Couverture de la Charge (Mix Énergétique)

L’analyse de la répartition des sources d’énergie (Energy to Load) valide la pertinence du dimensionnement du stockage. Le graphique tricolore ci-après décompose l’origine de l’électricité consommée par les bornes :
— Bleu foncé (Système PV) : L’autoconsommation directe est majoritaire durant les mois ensoleillés.
— Gris (Batteries) : Le stockage joue un rôle tampon crucial, assurant la fourniture d’énergie lors des pics de demande (Peak Shaving) et en soirée, réduisant ainsi la puissance souscrite nécessaire.

— Bleu clair (Réseau/Grid) : Le réseau reste indispensable pour assurer la continuité de service en hiver et la nuit, mais son sollicitation est drastiquement réduite par rapport à une station sans PV.


Figure 5.8 – Répartition mensuelle de la couverture de charge (PV vs Batterie vs Réseau).

### 5.3.4 Indicateurs de Performance Économique

Au-delà de la faisabilité technique, la simulation SAM fournit les métriques financières justifiant l’investissement. Le tableau de synthèse ci-dessous met en exergue une rentabilité exceptionnelle pour ce type d’infrastructure :
— Temps de retour (Payback Period) : L’investissement initial est amorti en seulement 3.1 ans. Ce résultat s’explique par les économies substantielles réalisées sur la facturation (évitement des pénalités de dépassement de puissance et réduction des kWh facturés).
— Économies nettes : Le système permet une économie annuelle estimée à 116 451 $ (USD).
— Valeur Actuelle Nette (NPV) : Avec une VAN positive de plus de 869 k$, le projet est extrêmement créateur de valeur sur sa durée de vie (20-25 ans).


Figure 5.9 – Tableau des indicateurs clés de performance (KPI) et financiers.

# Chapitre 6

# Etude économique

Table 6.1 – Résumé du CAPEX H.T. du système photovoltaïque (MAD)

Description | Nombre | Prix Unitaire H.T. (MAD) | Prix Total H.T. (MAD)
Panneaux solaires JA Solar de type JAM66D46 -LB -740 W | 180 | 1.200,00 | 216.000,00
Câble solaire (10) | 340 m | 65,00 | 22.100,00
Structure (Support) | 1 | 106.560,00 | 106.560,00
Onduleur PV SUN2000-100KTL-M1 | 1 | 50.000,00 | 50.000,00
Smart Logger 3000A | 1 | 7.000,00 | 7.000,00
Transformateurs de courant | 3 | 1.200,00 | 3.600,00
DTS U666-H Smart Power Sensor | 1 | 3.500,00 | 3.500,00
Huawei Smart String ESS LUNA2000-200KWH-2H1 | 2 | 800.000,00 | 1.600.000,00
Installation (Main d’œuvre / Ingénierie) | 1 | 159.840,00 | 159.840,00
TOTAL CAPEX H.T. | | | 2.168.600,00

Table 6.2 – Résumé du total avec TVA

Total H.T. | 2.168.600,00
TVA (20%) | 433.720,00
Total T.T.C. | 2.602.320,00

# Chapitre 7

# Conclusion

Le projet d’installation d’un système photovoltaïque autonome a été étudié et dimensionné avec précision, permettant de répondre efficacement aux besoins énergétiques tout en optimisant les coûts. Le CAPEX total du système s’élève à 2.168.600MAD, et l’analyse économique démontre une rentabilité remarquable.
L’évaluation financière montre que le système permet de réduire significativement la facture d’électricité, passant de 2.104.502MAD à 798.438MAD par an, générant des économies annuelles de 1.306.064MAD.
En conclusion, l’investissement dans ce système photovoltaïque représente une solution durable, économiquement rentable et respectueuse de l’environnement, offrant un retour rapide sur investissement et une autonomie énergétique importante pour les 25 prochaines années.

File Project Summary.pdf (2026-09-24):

## Conception et Dimensionnement d’une Station de Recharge Hybride (PV + Stockage) : Stratégie de Gestion Intelligente pour Superchargeurs Tesla

### 1 + Contexte du Projet

Le projet se situe à la **Station Supercharger Tesla**, localisée sur la Route de Sefrou à Fès, directement adjacente au magasin KITEA Giant. Ce site stratégique accueille des bornes de recharge ultra-rapides (Superchargers V2/V3) dont les appels de puissance massifs (jusqu’à 150 kW) créent des contraintes majeures :
- Saturation Réseau : Risque pour le transformateur local lors des charges simultanées.
- Coûts : Factures élevées dues aux pénalités de dépassement de puissance.

### 2 Solution Technique

Nous proposons la conversion du site en Hub Énergétique Intelligent. L’architecture repose sur l’exploitation de la toiture du KITEA voisin pour la production solaire, reliée à un système de stockage industriel situé près des bornes, le tout géré en Couplage AC.

Ô Caractéristiques Techniques Dimensionnement

Le Générateur Photovoltaïque (Toiture KITEA)

✓ Technologie : Monocristallin Haute Efficacité.
✓ Modules : 180 × JA Solar JAM66D46 740W.
✓ Puissance Totale : 133,2 kWc.
✓ Conversion : 1 × Huawei SUN2000-100KTL-M1.

C Le Stockage Industriel (Station Tesla)

✓ Matériel : 2 × Huawei LUNA2000-200KWH-2H1. ✓ Capacité : 387 kWh (Autonomie pour ≈ 6 véhicules). ✓ Puissance de Décharge : 200 kW (Peak Shaving).

Z Architecture Câblage

✓ Liaison Distance : 100 m (KITEA → Station). ✓ Câble de Puissance : 4x50 mm² Cuivre.
✓ (Note : Section calculée min. 40 mm²

, standardisée à 50 mm²
).
✓ Point de Couplage : TGBT Station (Bus AC Commun).

1

### 3 j Stratégie de Gestion (EMS)

Le système est piloté par le SmartLogger 3000A selon trois modes prioritaires :
¢ Peak Shaving | Injection immédiate des batteries si la demande dépasse le seuil critique, protégeant le réseau RADEEF.
Â Arbitrage | Utilisation de l’énergie solaire stockée pendant les heures de pointe (soir) pour éviter la tarification onéreuse.
Net-Zero | Compensation carbone des recharges Tesla par la production solaire verte locale.

2

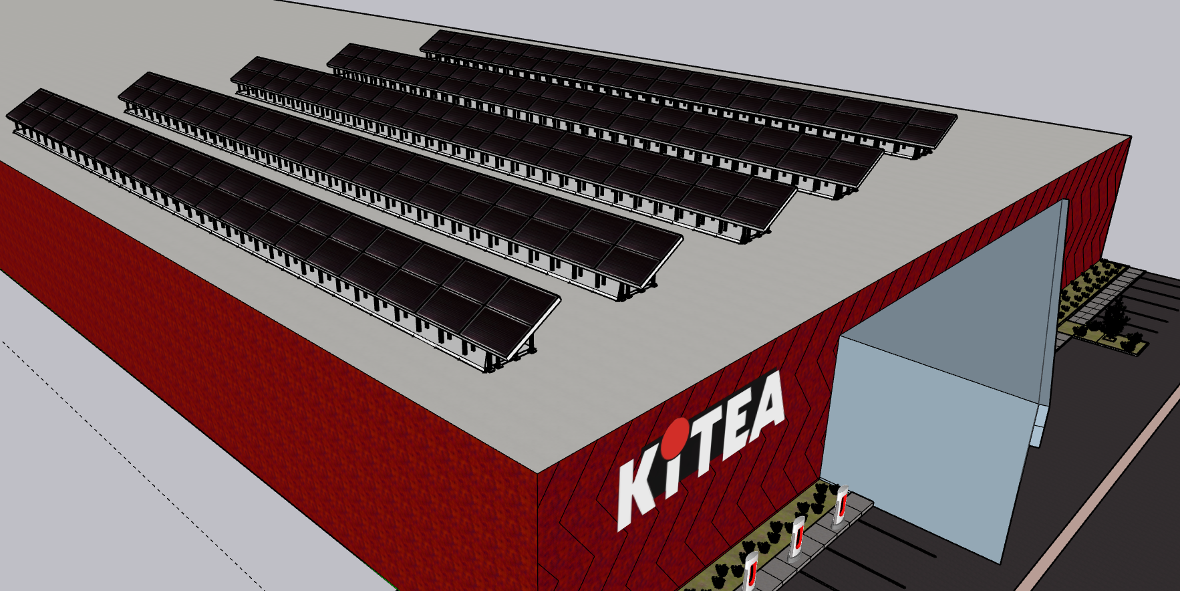
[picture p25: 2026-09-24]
SketchUP/Capture d_écran 2025-12-01 224916.png

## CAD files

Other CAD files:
Autocad/simulations/schema unifilaire puissance.dwg
Autocad/simulations/schema Multiifilaire puissance.dwg
Autocad/simulations/les vues de systeme.dwg
Autocad/simulations/schema unifilaire.dwg
Autocad/simulations/Support 2D.dwg
Autocad/simulations/schema Multiifilaire comande.dwg
Autocad/simulations/schema unifilaire commande.dwg
SketchUP/SketchUP.skp

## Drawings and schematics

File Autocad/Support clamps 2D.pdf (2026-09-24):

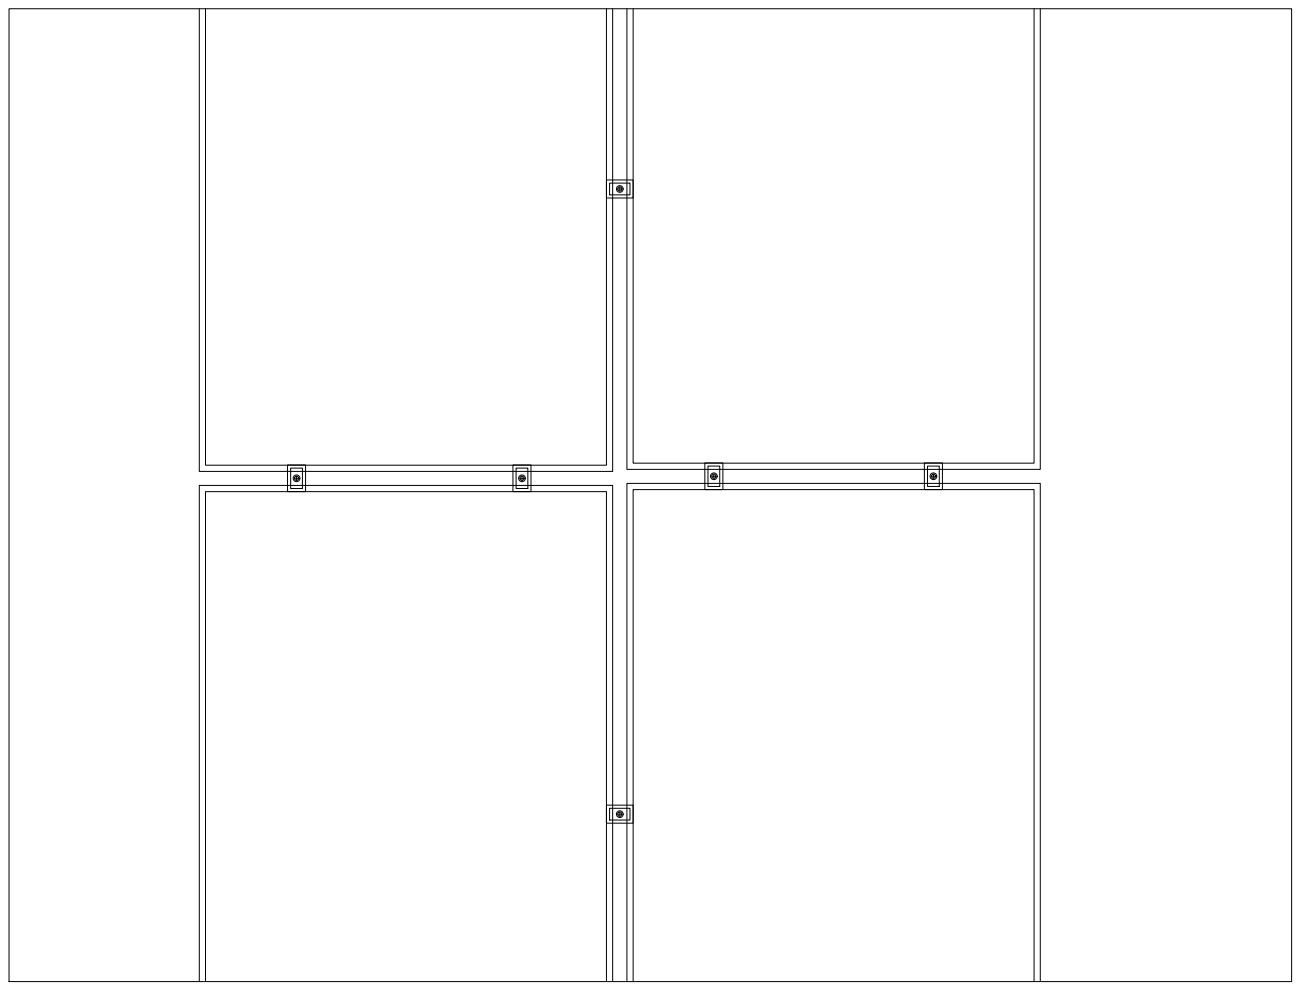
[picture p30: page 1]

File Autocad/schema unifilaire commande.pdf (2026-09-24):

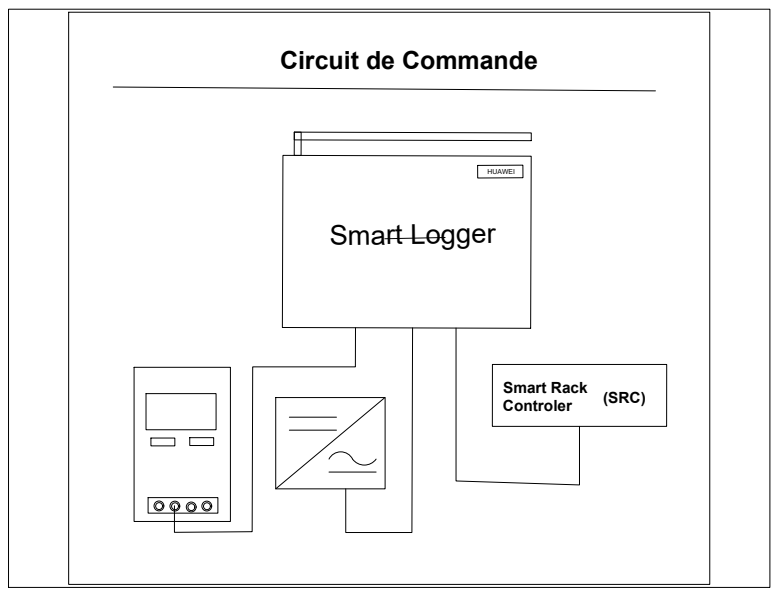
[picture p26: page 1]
HUAWEI Smart Logger Smart Rack Controler; (SRC) Circuit de Commande

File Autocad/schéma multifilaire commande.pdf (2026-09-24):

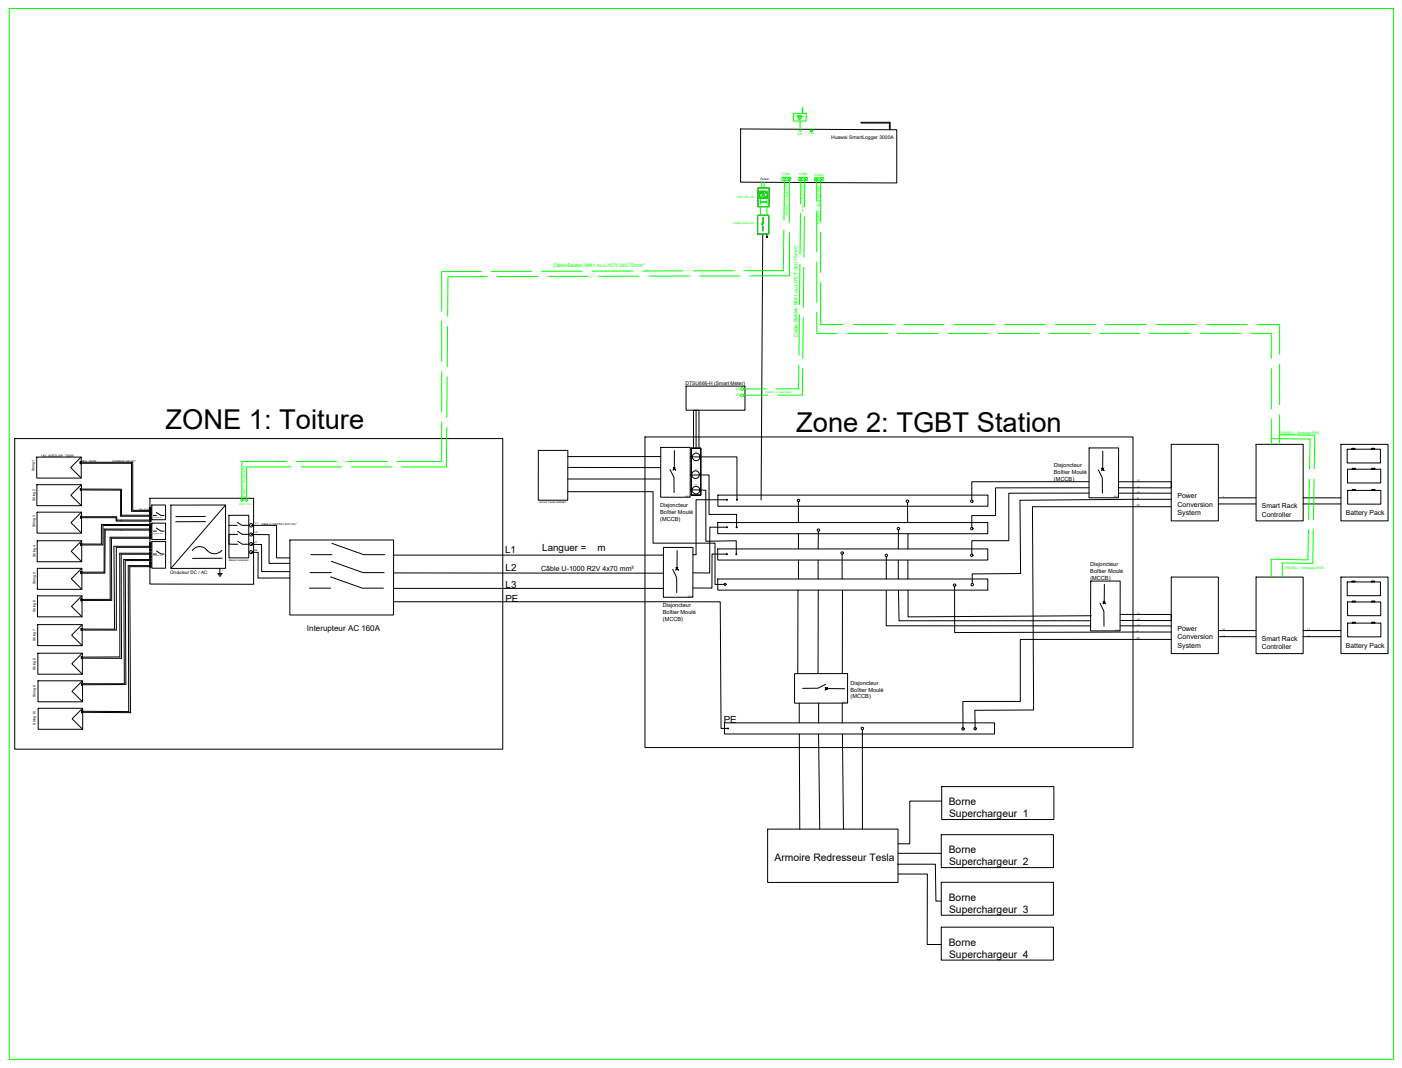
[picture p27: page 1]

String 1 String 2 String 3 String 4 String 5 String 6 String 7 String 8 String 9 String 10 Interrupteur DC 1 Interrupteur DC 2 Interrupteur DC 3 Onduleur DC / AC Relais d isolement L1 L2 L3PE Interupteur AC 160A L3L2L1 18x JASOLAR 740W ZONE 1: Toiture MC4 - EVO2 MC4 - EVO2 H1Z2Z2-K 1x6 mm² Câble U-1000 R2V 4x70 mm² Cu 16 mm PE Languer = m Câble U-1000 R2V 4x70 mm² PE Disjoncteur Boîtier Moulé (MCCB) 160 A Disjoncteur Boîtier Moulé (MCCB) 160 A Arrivée Transfo RADEEF DTSU666-H (Smart Meter) TC L3 TC L2 TC L1 L1L2L3 Power Conversion System L1L2 Smart Rack Controller Battery Pack L1L2 L1L2L3 Power Conversion System +- Smart Rack Controller Battery Pack PENPEN 160 A Disjoncteur Boîtier Moulé (MCCB) 160 A Disjoncteur Boîtier Moulé (MCCB) +- Zone 2: TGBT Station 160 A Disjoncteur Boîtier Moulé (MCCB) Armoire Redresseur Tesla Borne Superchargeur 1 Borne Superchargeur 2 Borne Superchargeur 3 Borne Superchargeur 4 Power Disjoncteur 2A Alim 24V DC COM1 COM2 COM3 + - + - + - Pins 1 & 3 RS485-1 : Onduleur PV RS485-1 : Onduleur PV RS485-2 : Stockage ESS RS485-2 : Stockage ESS RS485-2 : Stockage ESS 2425 RS485-3 : Power Meter RS485-3 : Power Meter WANRouteur Internet 4G Station

Câble Ethernet RJ45 Huawei SmartLogger 3000A Câble Belden 9841 ou LiYCY 2x0.75mm² Câble Belden 9841 ou LiYCY 2x0.75mm²

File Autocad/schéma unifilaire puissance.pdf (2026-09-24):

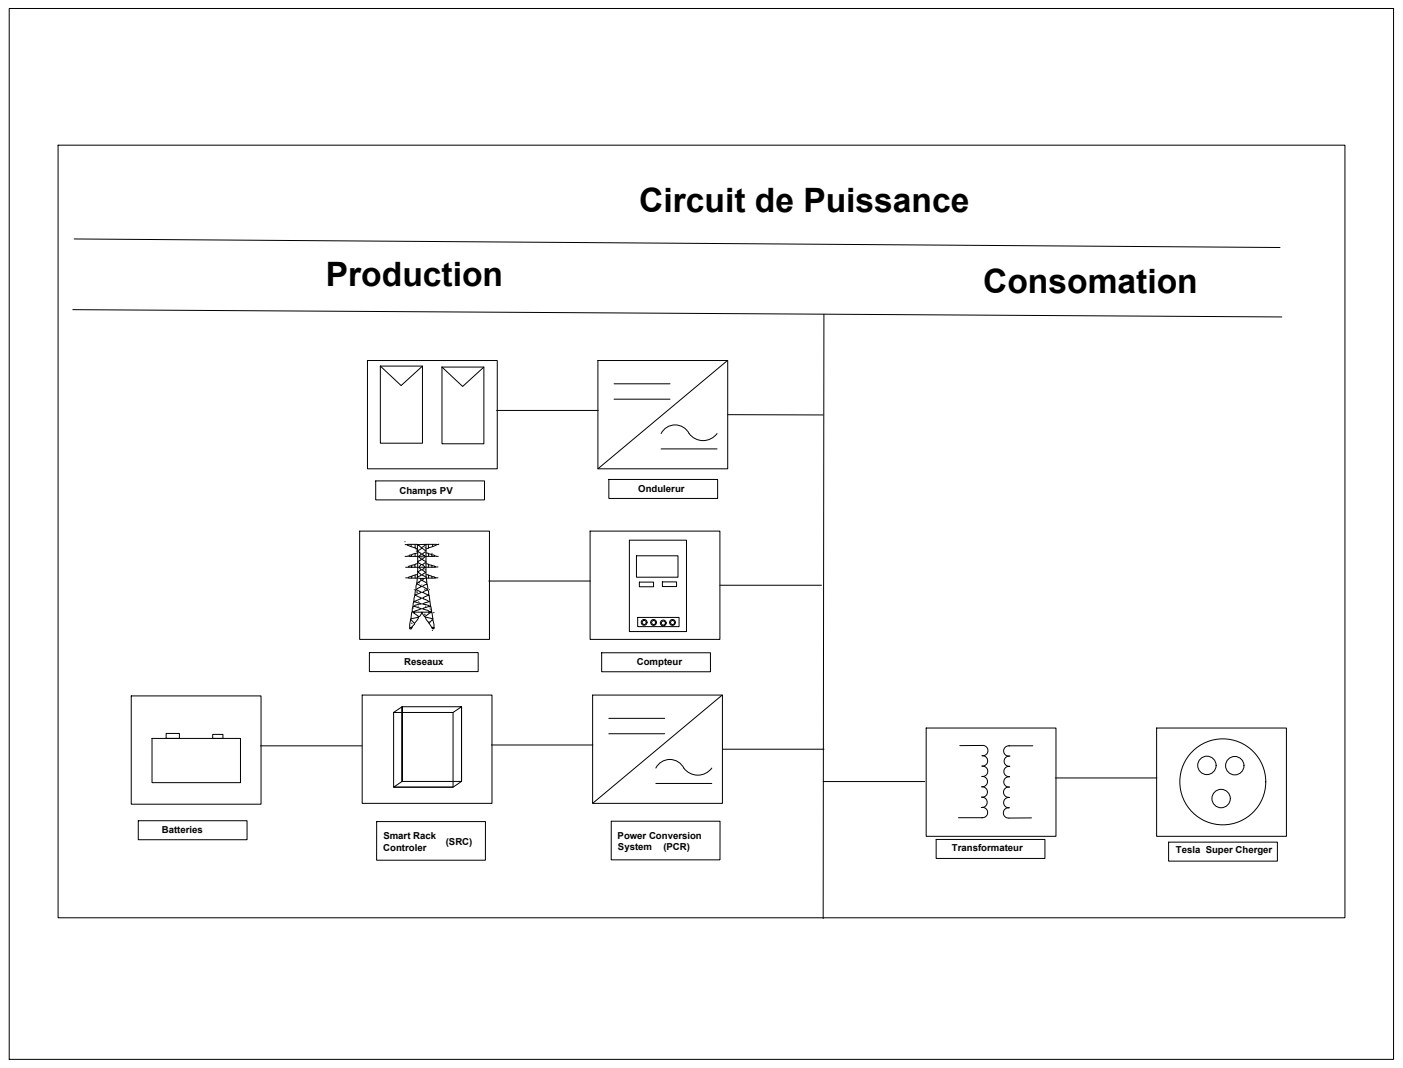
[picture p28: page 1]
Champs PV; Ondulerur Reseaux; Compteur; Transformateur; Tesla Super Cherger Production; Consomation Smart Rack Controler Batteries; (SRC); Power Conversion System; (PCR) Circuit de Puissance

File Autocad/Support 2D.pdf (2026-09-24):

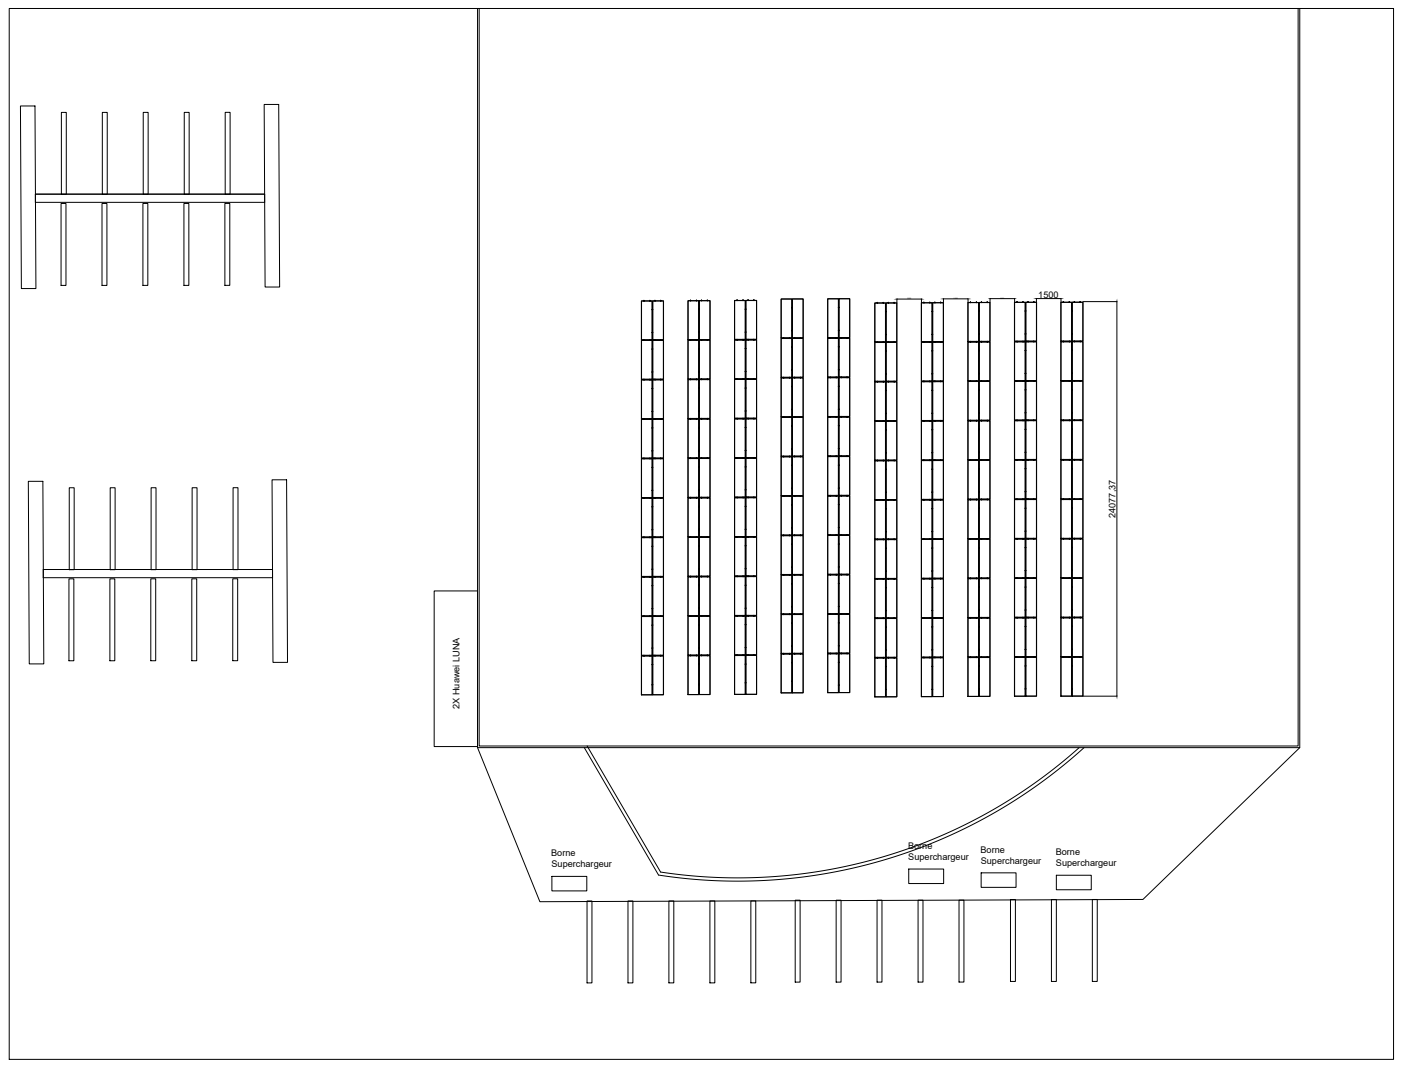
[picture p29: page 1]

2X Huawei LUNA Borne Superchargeur Borne Superchargeur Borne Superchargeur Borne Superchargeur

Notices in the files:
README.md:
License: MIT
